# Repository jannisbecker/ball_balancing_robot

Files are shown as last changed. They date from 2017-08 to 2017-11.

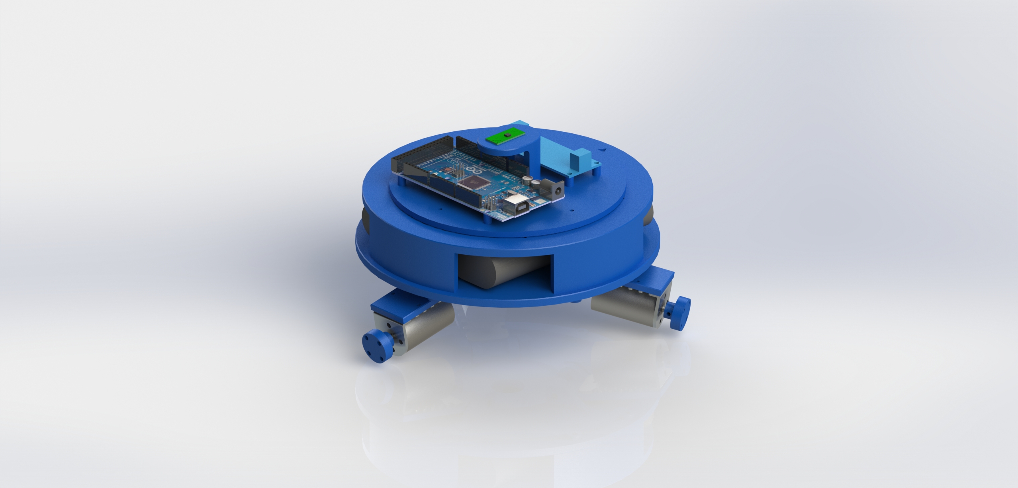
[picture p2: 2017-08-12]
cad/rendering2.jpg

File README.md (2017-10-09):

Repo imported from my old account https://github.com/kekx/ball_balancing_robot

# Ball Balancing Robot

A project made and built by two people, Jannis Becker and Susanne Totz,
in the 6th semester of "Visual Computing and Design" at the Hochschule Hamm-Lippstadt in Germany.

More info on the given task, the project itself and the challenges we faced
can be found in the technical documentation.

## File tree

* **additions**
  * **arduino test sketches:** contains various little code snippets used to test hardware functionality and software concepts.
  * **gyro calibration utility:** java source for a serial data plotter used for calibrating the IMU. More info in the tech doc.
* **cad:** Contains the most recent set of SolidWorks 2017 project files. "Bottom Plate Rework Assembly.SLDASM" being the main file to be opened here.
  * **old versions:** Previous prototypes of the design, including a now unused omniwheel design and the first and second prototype iterations.
  * **thin plates:** Modified files that ended up being used, as the thick plates of the original design couldn't be printed. As seen in the media files, we ended up using thin printed parts and filling the space up with 3mm wooden plates.
* **doc:** The technical documentation containing lots of further insights into the project (German).
* **media:** Videos and photos of the final robot build.
* **src:** Final arduino code.

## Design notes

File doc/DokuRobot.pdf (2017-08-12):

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

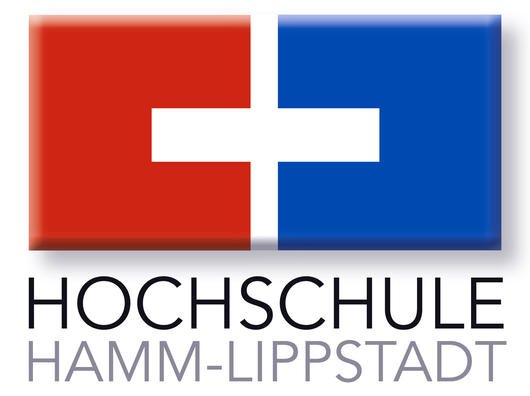
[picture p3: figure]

## Inhaltsverzeichnis

1 Einleitung | 1
2 Problembeschreibung | 2
3 Realisierung des Ball Balancing Robot | 4
4 Fazit | 21
5 Sonstiges | 24
Anhang | 25

I

## 1 Einleitung

Im Rahmen des Wahlpichtfaches Ubiquitous Computing im 6. Semester des Studiengangs

Computervisualistik und Design ist das Projekt Ball Balancing Robot entstanden. Die Auf-

gabenstellung besagte, dass die Studenten zusammen in Gruppen einen Hardwareprototypen

planen, bauen und letztlich mit einer eigens entwickelten Software lauähig machen sollen. Die

Wahl des Themas und der Systemumgebung war den Studenten dabei selbst überlassen. Als

Hilfestellungen konnten Internetquellen und Literatur verwendet werden.

Das Ziel dieses Projektes war es, einen mobilen Roboter zu entwickeln, der eigenständig auf

einem Ball balancieren und sich bei einer externen Krafteinwirkung auch möglichst selbst wie-

der ausrichten kann. Inspiriert wurden wir hierbei durch ein Projekt an der Tohoku Gakuin

Universität in Tagajo, Japan, geleitet von Dr. Masaaki Kumagai, der zusammen mit einem

Studententeam selbst einen solchen Roboter entwickelt hat. 1

Dieses entwarf eine Plattform, die, angetrieben von drei mit sogenannten Allseitenrädern be-

stückten Schrittmotoren, auf einer mit Gummi beschichteten Bowlingkugel balancieren und sich

auch selbst oder per Steuerbefehl im Raum bewegen kann. Dieser Roboter ist auÿerdem in der

Lage, Objekte mit bis zu 10kg Gewicht zu transportieren und kann damit sowohl eigenständig

oder als maschinelle Unterstützung für den Lastentransport eingesetzt werden.

Die zugrunde liegende Funktionsweise eines solchen, sogenannten omnidirektionalen Roboters

wurde in den 70er Jahren entwickelt. Heutzutage haben bereits viele Studentengruppen, aber

auch Hobbyentwickler sich einem solchen Projekt angenommen und es existieren zahlreiche

Berichte und Dokumentationen über diese im Internet. So ist auch dieses Team über einige

Internetquellen sowohl auf das Projekt von Dr. Kumagai, als auch andere Nachbauten gestoÿen

und wurde somit inspiriert, selbst einen solchen Roboter zu entwickeln.

1http://spectrum.ieee.org/automaton/robotics/robotics-software/042910-a-robot-that-balances-on-a-ball

Gegenüber anderen beweglichen Robotiksystemen hat eine omnidirektionale Plattform einige

entscheidende Vorteile. So können diese ohne Verzögerung und jegliche Änderung der Blickrich-

tung direkt in alle Richtungen bewegt werden und sind somit äuÿerst agil. Zudem können diese

Roboter je nach Bauweise sehr klein und mobil gestaltet werden, weshalb sie für zahlreiche

Aufgaben in den unterschiedlichsten Bereichen infrage kommen.

Neben den zu implementierenden Funktionen der Balancehaltung und der Bewegung kann dieses

System auÿerdem noch um viele Funktionen erweitert werden, wie z.B. das ferngesteuerte oder

autonome Fahren, sowie weitere Sensorik und Aktorik.

## 2 Problembeschreibung

In diesen Abschnitt wird kurz dargestellt, welche Quellen das Team nutzt, um den Balancing

Robot zu realisieren. Ebenso werden die Risiken erläutert, die während der Implementierung

Hard- und Software auftreten können.

Die grundlegende Architektur lehnt sich an das Projekt von Dr. Kumagai an, da diese eine

sehr gut funktionierende, aber auch vergleichsweise einfach zu implementierende Basis bildet.

So werden drei Motoren und Räder verwendet, angeordnet in einem 120◦ Winkel zueinander.

Es gibt durchaus auch einige Ansätze, welche zwei oder vier Antriebe verwenden würden, wobei

wir ersteres aufgrund der fehlenden Stabilität und letzteres wegen dem zusätzlichen Kostenauf-

wand sowie Stromverbrauch für ungeeignet hielten. Auch die restliche Hardware, wie z.B. die

benötigte Sensorik und der Mikrocontroller wurden für dieses Projekt eigens ausgewählt, um

optimale Kompatibilität mit unserer Plattform und der gewählten Umgebung zu gewährleisten.

Die Verarbeitung und Ansteuerung in der Software funktioniert grundlegend wie folgt: Zuerst

wird ein Lagesensor nach der aktuellen Rotation des Roboters gefragt. Diese Daten werden

dann in einem Regler weiter verarbeitet und zuletzt an die Motoren gegeben, die eine Schief-

lage dann ausgleichen. Dieser Ablauf ndet viele Male pro Sekunde statt, sodass der Roboter

seine Position und Rotation kontinuierlich ausgleicht.

Die Risiken in der Implementierung der Software stecken vor allem darin, dass der Datenuss

nicht einwandfrei funktionieren könnte. Die Messdaten enthalten Schwankungen und können

von der Nullposition abdriften. Dies gilt es zu erkennen und zu beseitigen. Auÿerdem müssen

mathematische Konventionen, Wertebereiche und Standards deniert werden, welche in allen

Datenströmen und Interfaces zwischen der Sensorik, Verarbeitung und Aktorik eingehalten

werden müssen. Ein falscher Wertebereich oder ein Vertauschen von Datenströmen kann hier

bereits zu einem sehr willkürlich wirkenden Verhalten des Roboters und daraus folgend einem

sehr aufwendigen und zeitintensivem Debugprozess führen.

Da diese Roboter kontinuierlich gegen Schwankungen in jegliche Richtungen, als auch gegen die

Schwerkraft arbeiten muss, sollte bei der Gestaltung des Gerüsts und dem Einbau der Hardware

insbesondere auf die radiale Gewichtsverteilung, aber auch die Verteilung in unterschiedlichen

Höhen geachtet werden. Eine falsche Aufteilung kann hier entweder zu einem nicht genügend

trägen Verhalten führen, da eine gewisse Trägheit für das System benötigt wird, oder aber zu

einem radialen Ungleichgewicht führen, welches die Steuerung des Roboters prinzipiell sehr viel

schwieriger, wenn nicht sogar unmöglich machen würde.

Das Zeitmanagement ist gerade besonders bei Projekten wichtig, in dem vorwiegend Studenten

zusammen arbeiten, die unterschiedliche Erfahrungen in Umgang mit Software und eingebet-

teten System mitbringen. Die Implementationsphase der Software könnte sich schon aufgrund

der Tatsache verzögern, dass die Programmiersprache C/C++ eingesetzt werden muss und die-

se mit einem gewissen Lernaufwand verbunden ist. Die Beschaung der Hardwarebestandteile

sowie das Design des Robotergerüsts benötigen zusätzlich Zeit, weshalb die Entwicklung des

Roboters in unterschiedlichen Phasen unterteilt wird, damit das gesamte Projekt fristgerecht

abgeschlossen werden kann.

## 3 Realisierung des Ball Balancing Robot

In diesem Teil der Ausarbeitung werden die Umsetzungsphasen im Projekt Balancing Robot

aufgegrien und beschrieben. Die Phasen fanden teilweise parallel statt und können somit nur

eingeschränkt unabhängig von einander betrachtet werden.

3.1 | Entwicklung der Gestalt des Roboters
3.1.1 | Allgemein

Folgende Punkte sind bei der Gestaltung des Ball Balancing Robot zwingend zu beachten, um

die Funktionsfähigkeit des Roboters zu gewährleisten:

- Der Roboter benötigt in alle Richtungen eine gleichmäÿige Gewichtsverteilung, damit er
| seine eigene Masse auf dem Ball ausbalancieren kann.
- Die Einbettung des Hardwaresystem mit seinen gesamten Bestandteilen benötigt viel
| Platz, daher ist dieser Sachverhalt bei der Erstellung des Robotergerüsts zu berücksich- tigen. Idealerweise sollte der Roboter nicht in die Breite, sondern in die Höhe, mithilfe mehrerer Ebenen für die verschiedenen Komponenten, gestaltet werden. Somit wird auch die Verwendung kleinerer Bälle ermöglicht und der Roboter ist allgemein mobiler und agiler.
- Die Gewichtsverteilung auf den Ebenen spielt ebenfalls eine wichtige Rolle, um den Ro-
| boter vor dem Umkippen zu bewahren. Eine möglichst hohe Trägheit im Vergleich zum Ball gewährleistet, dass der Ball sich unter dem Roboter bewegen kann, und somit ei- ner Übersteuerung der Motoren entgegen gewirkt wird. Auÿerdem lieÿe sich eine externe Steuerung des Roboters andernfalls nicht realisieren. Dazu müssen die schweren Akkus möglichst weit unten nahe am Ball platziert werden und die leichte Elektronik und Sen- sorik nden weiter oben ihren Platz. Zusätzlich bewirkt ein Platzieren des Lagesensors in gröÿerer Entfernung zum Ball einen gröÿeren Ausschlag der Werte, was eine einfachere Auswertung und eine direktere Steuerung ermöglicht.

3.1.2 Prototyp 1

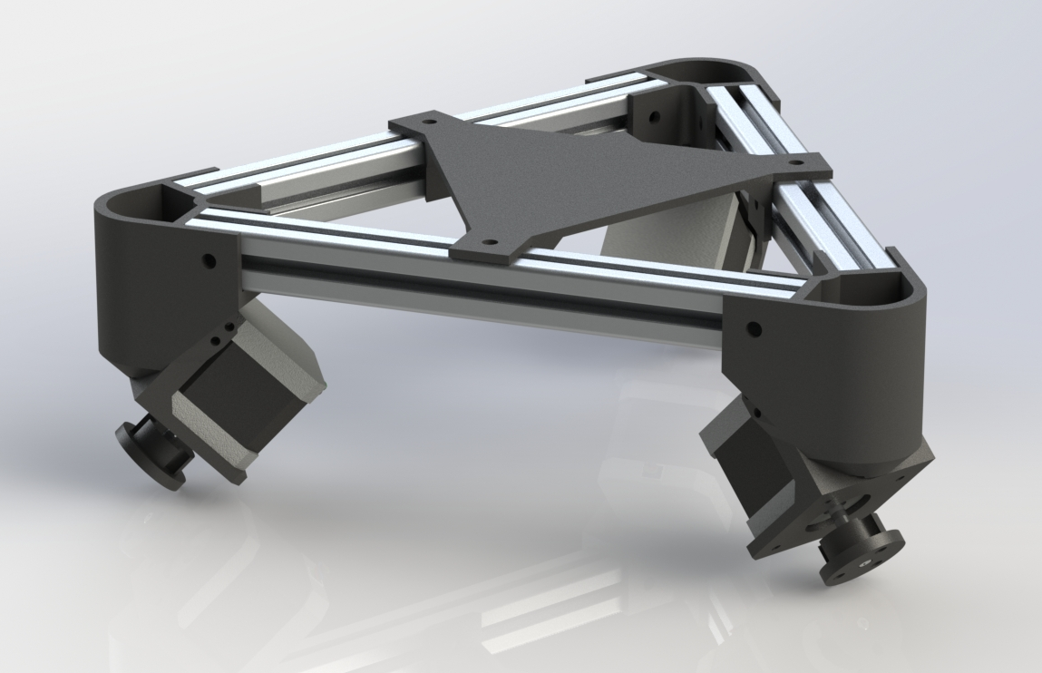
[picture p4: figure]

Abbildung 1: Der nicht vollendete erste Prototyp

Der erste Prototyp (Abb. 1) basierte einer dreieckigen Basis, die aus 20*20 mm groÿen Ex-

trusionsprolen aus Aluminium bestand. Dieses Grundgerüst war an die sehr ähnliche, übliche

Bauweise von Delta 3D-Druckern angelehnt. Der Prototyp war optimiert für den Einsatz

von Schrittmotoren (siehe Abschnitt Hardware). Die Motoren wurden dabei auf drei Schlitten

montiert, die in einem 45◦ Winkel an das Robotergehäuse angebracht sind. Der Vorteil dieser

Montage ist die einfache Wartbarkeit. (Abb. 2) Das Hardwaresystem, sowie alle anderen not-

wendigen Bestandteile wie die Stromversorgung nden ihren Platz in der mittleren Plattform

und der darunter liegenden Ebene.

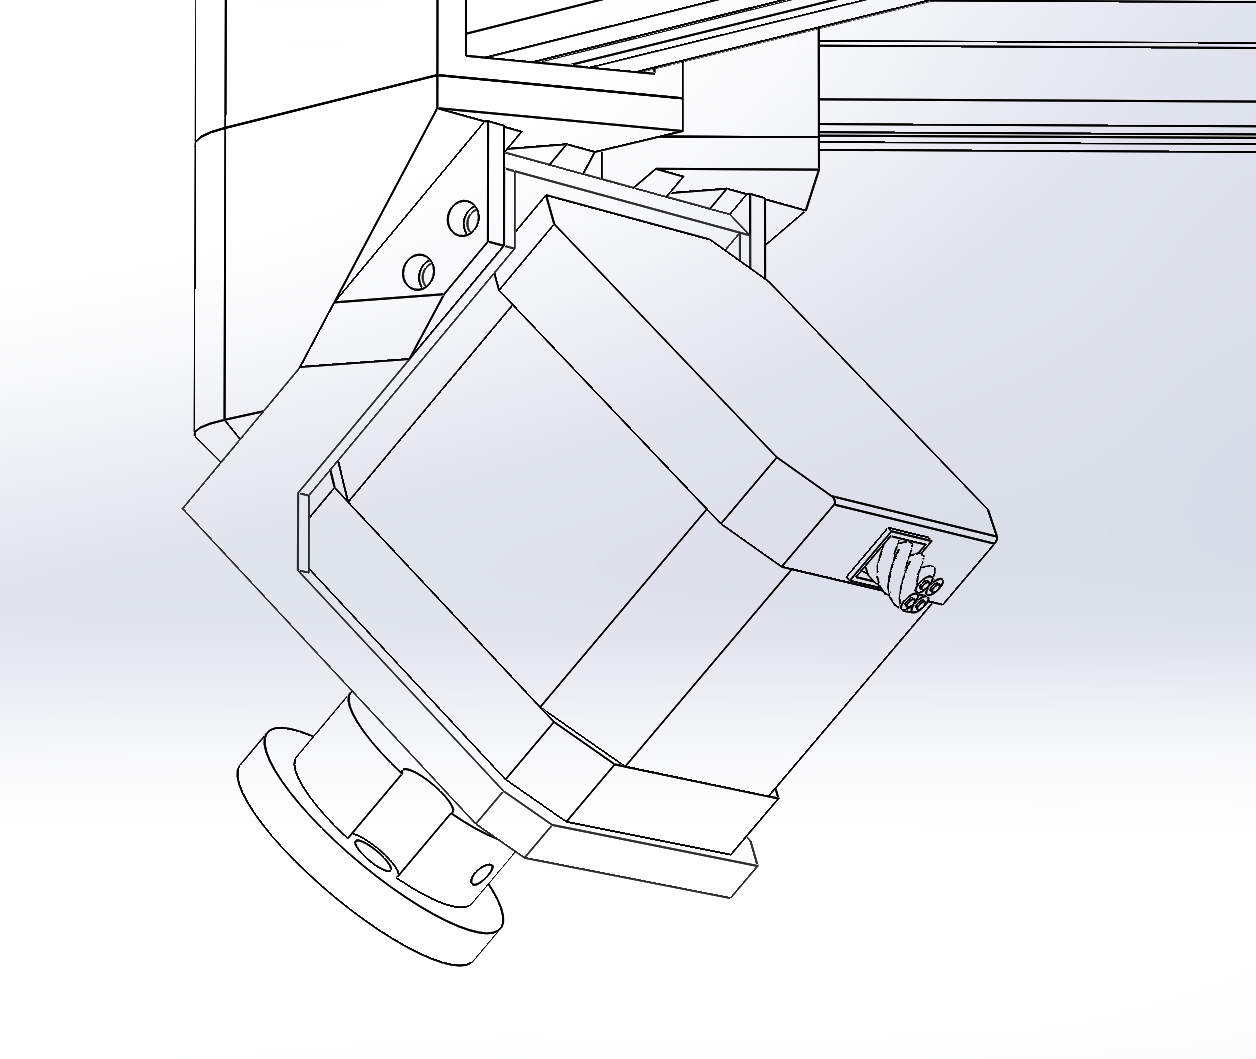
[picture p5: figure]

Abbildung 2: Die Befestigung des Motors beim ersten Prototyp

Folgende Vorteile erhoten wir uns von diesem Prototypen:

- Die Aluminiumprole waren bereits vorhanden, somit hätten weniger Teile nachproduziert

(gedruckt) werden müssen.

- Das Gehäuse bestünde aus Aluminium und wäre damit sehr stabil und widerstandsfähig.
- Durch den Einsatz von starken Schrittmotoren wäre ein Lastentransport möglich gewesen.

Durch die folgenden Nachteile haben wir uns jedoch gegen die Nutzung dieses Prototyps ent-

schieden:

- Die gesamte Konstruktion wäre sehr groÿ gewesen. Die vorhandenen Prole sind 20cm

lang, woraus sich ein Gesamtdurchmesser von etwa 30cm ergibt. Da der Ball somit eben-

falls gröÿer ausfallen muss, gäbe es einen groÿen Einbuÿen in der Mobilität des Roboters.

- Das hohe Gesamtgewicht der Konstruktion und der Schrittmotoren u.A. hätten die Be-

wegung erschwert und das System weniger reaktionsfähig gemacht.

- Da der Fokus bei dieser Variante auf der Breite statt auf der Höhe liegt, wären die Trägheit

und die Gewichtsverteilung des Systems nicht optimal gewesen und die Ausbalancierung

der Komponenten würde erschwert.

3.1.3 Prototyp 2

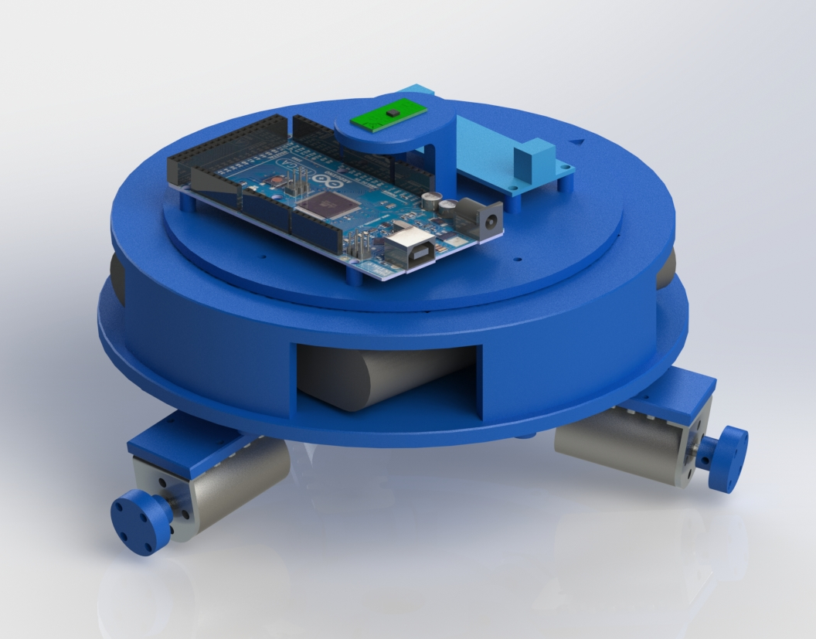
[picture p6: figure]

Abbildung 3: Das Rendering des vollendeten zweiten Prototyps, inklusive der meisten Hardware

Aufgrund der Nachteile der ersten Variante ist die Entscheidung gefallen, ein kreisförmiges

Grundgerüst zu entwerfen (Abb. 3), bestehend aus leichtem, jedoch stabilem Kunststo, welches

vollständig mithilfe eines 3D-Druckers hergestellt werden kann. Die direkte Verfügbarkeit dessen

begünstigte diese Entscheidung wesentlich.

Der Prototyp Nr. 2 hat die folgenden Vorteile gegenüber dem ersten:

- Die Grundform des Gehäuses eignet sich besser zum Anordnen der Hardwarebestandteile

und der Stromversorgung.

- Die mehrschichtige Konstruktion lässt eine präzisere, vertikale Gewichtsverteilung zu

(Trägheitsoptimierung) und ermöglicht eine bessere Balance in der Horizontalen.

- Sehr viel schmaler, mit eng aneinander liegenden und justierbaren Motoren, daher ist

dieser Prototyp für viele Ballgröÿen geeignet.

- Die Konstruktion ist insgesamt leichter, kleiner und agiler, dies sorgt dafür, dass die

Reaktionen schneller und die Bewegung üssiger sind.

Jedoch gibt es auch hier den folgenden, jedoch vernachlässigbaren Nachteil:

- Die Konstruktion ist aufgrund der gewählten Materialien etwas instabiler. Somit ist even-

tuell der Lastentransport nicht gewährleistet. Trotz der Kunststokonstruktion ist aber

mit Hilfe von Verstärkungsrippen, Verrundungen u.Ä. für ausreichende Stabilität gesorgt.

3.1.4 Aufbau des Prototyp 2 im Detail

Im Folgenden ist der grundlegende Aufbau der einzelnen Ebenen des zweiten Prototyps be-

schrieben. Die Ebenen werden hier einzeln von unten nach oben betrachtet.

1. Abb. 4: Drei Motoren inklusive Halterungen und angebrachten Adaptern für die Rä-
| der, befestigt mit drehbaren Verbindungen an der unteren Grundplatte. Zu sehen sind
| hier auÿerdem die Verstärkungsrippen, die Schraubenlöcher zur Befestigung der weiteren
| Schichten, sowie das zentrale Loch für die Kabelführung.
2. Abb. 5: Obere Grundplatte, inklusive äuÿeren und inneren Stelzen, damit zwischen
| oberer und unterer Platte Hardware untergebracht werden kann. Auch hier sieht man das
| zentrale Loch für die Kabelführung, die benötigten Schraublöcher, sowie weitere, eckige
| Löcher, welche später Kabelbinder führen, um die Akkupacks zu befestigen.
3. Abb. 6: Weiterhin die obere Grundplatte, Ansicht von oben. Hier sieht man sehr gut die
| Vertiefungen für die Kabelbinder, damit direkt darauf auiegend die weiteren Ebenen
| befestigt werden können. Eine pfeilförmige Vertiefung symbolisiert die mathematische
| Vorderseite des Roboters.
4. Abb. 7: Befestigungsplatte mit Abstandshaltern, auf dem der Arduino Mega und der
| Spannungsregler befestigt werden. Der Kabelkanal wird hier zu einem Langloch, um das
| seitliche Herausführen der Kabel auf dieser obersten Ebene zu ermöglichen. Nicht alle
| Abstandshalter sind vorgebohrt, da die entsprechenden Schraubenlöcher auf dem Arduino

durch zu kleine Abstände den SMD-Bauteilen nicht für Schrauben genutzt werden können.

Hier wird der Arduino dementsprechend nur aufgelegt. Die beiden Löcher neben der

Kabelführung verbinden später den sogenannten Gyroturm mit dieser Platte.

5. Abb. 8: Der Gyroturm dient der Befestigung des Gyrosensors auf einer erhöhten Ebene,

um dessen Präzision und die Reaktionsfreudigkeit des Gesamtsystems zu erhöhen. Das

rechteckige Loch auf der Oberseite besitzt ähnliche Maÿe wie die Stiftleiste unter der

Gyrosensorplatine und hält diesen somit in Position. Die entsprechenden Pins stehen nun

aus der Unterseite des Turms hervor, wo sie per Jumperkabel mit dem darunterliegenden

Arduino verbunden werden können. Das Loch und der Turm selbst sind so platziert, dass

der eigentliche Gyrosensor IC auf seiner Platine möglichst exakt mittig über dem Roboter

liegt, sodass X und Y-Rotation des Sensors bei einer Bewegung gleichmäÿig ausschlagen.

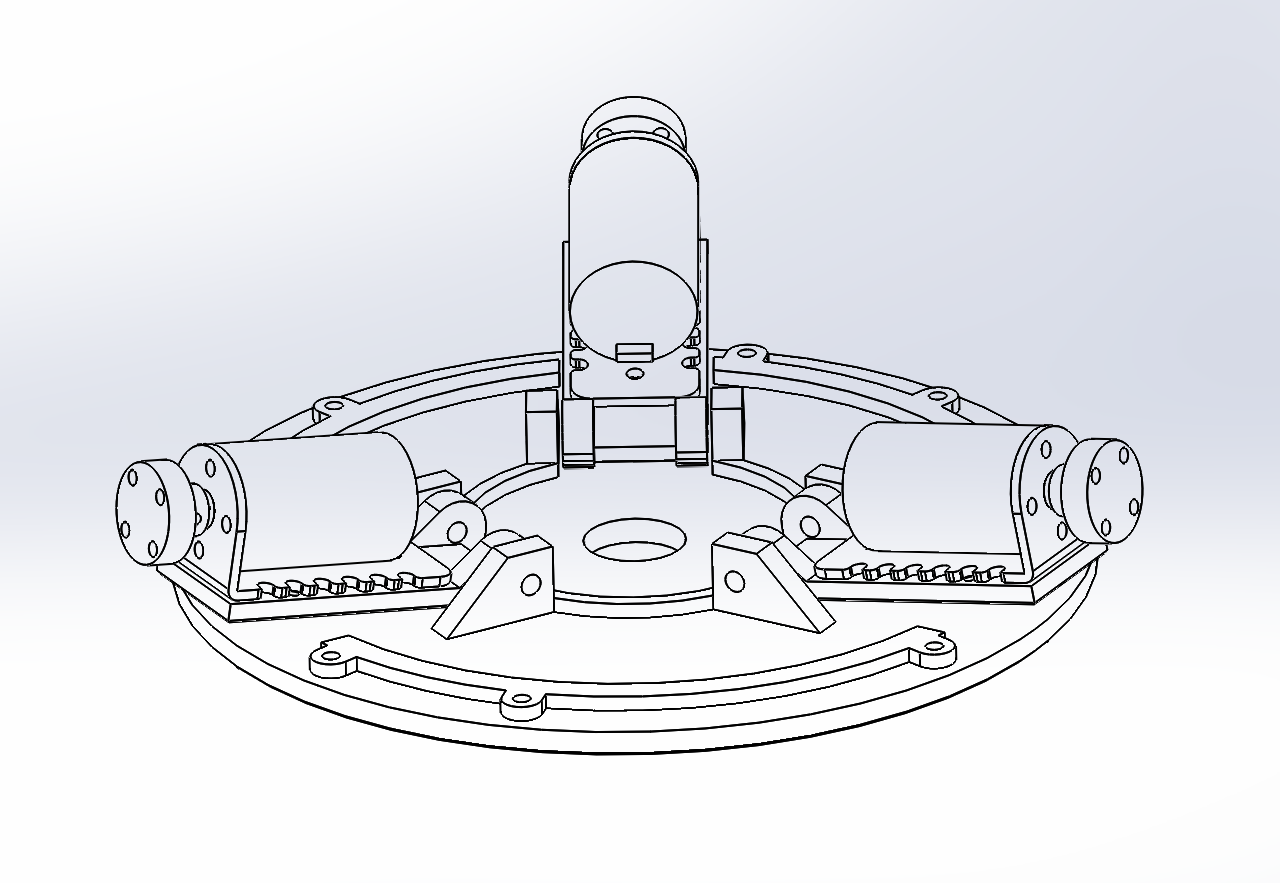
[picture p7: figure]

Abbildung 4: Eine Skizze der unteren Grundplatte, inklusive Motoren und Halterungen, Ansicht von Unten

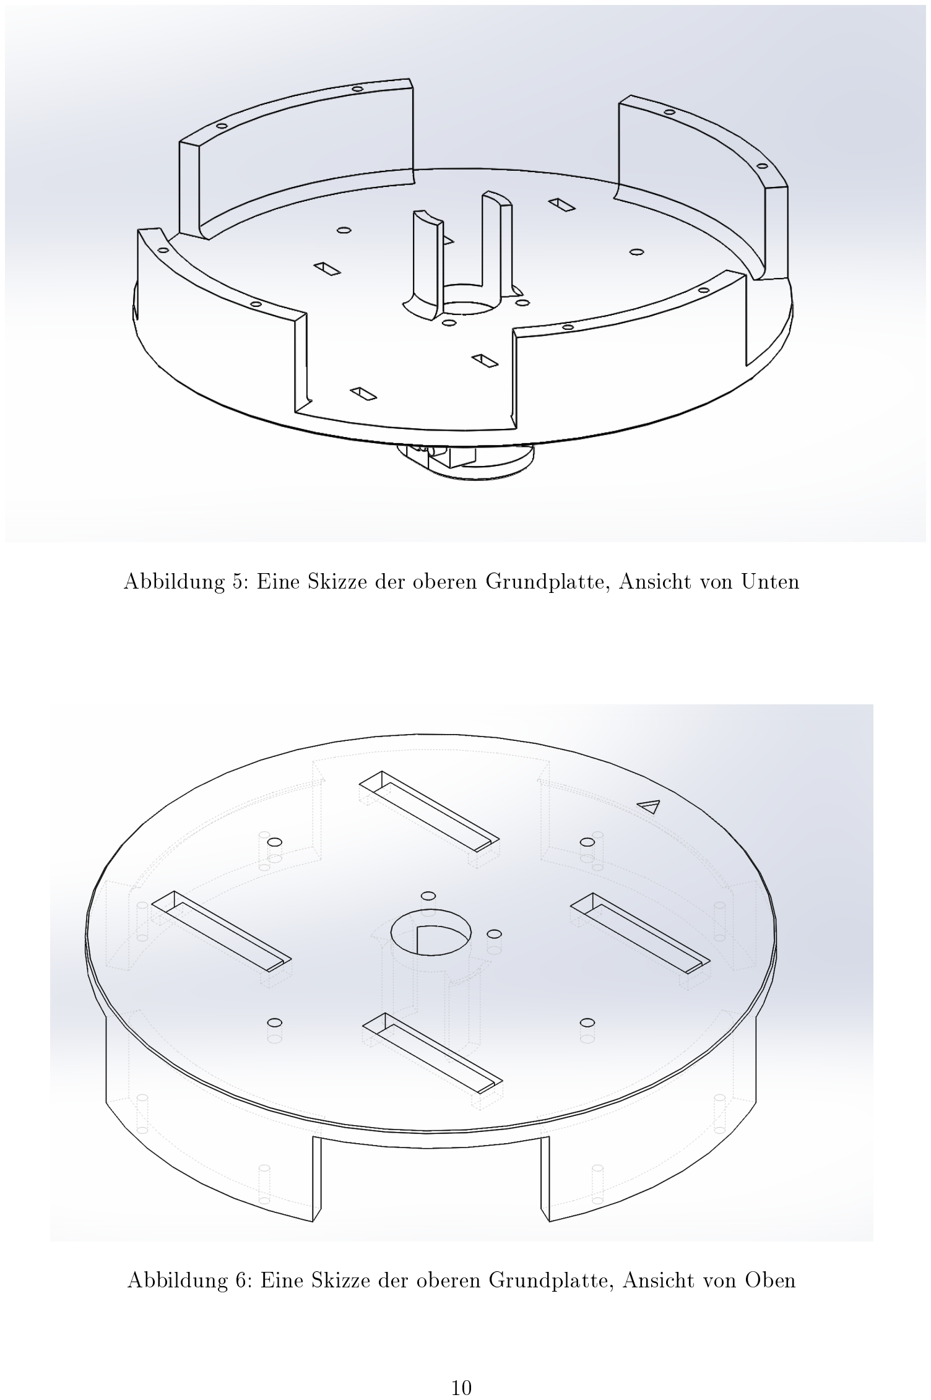
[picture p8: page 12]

Abbildung 5: Eine Skizze der oberen Grundplatte, Ansicht von Unten

Abbildung 6: Eine Skizze der oberen Grundplatte, Ansicht von Oben

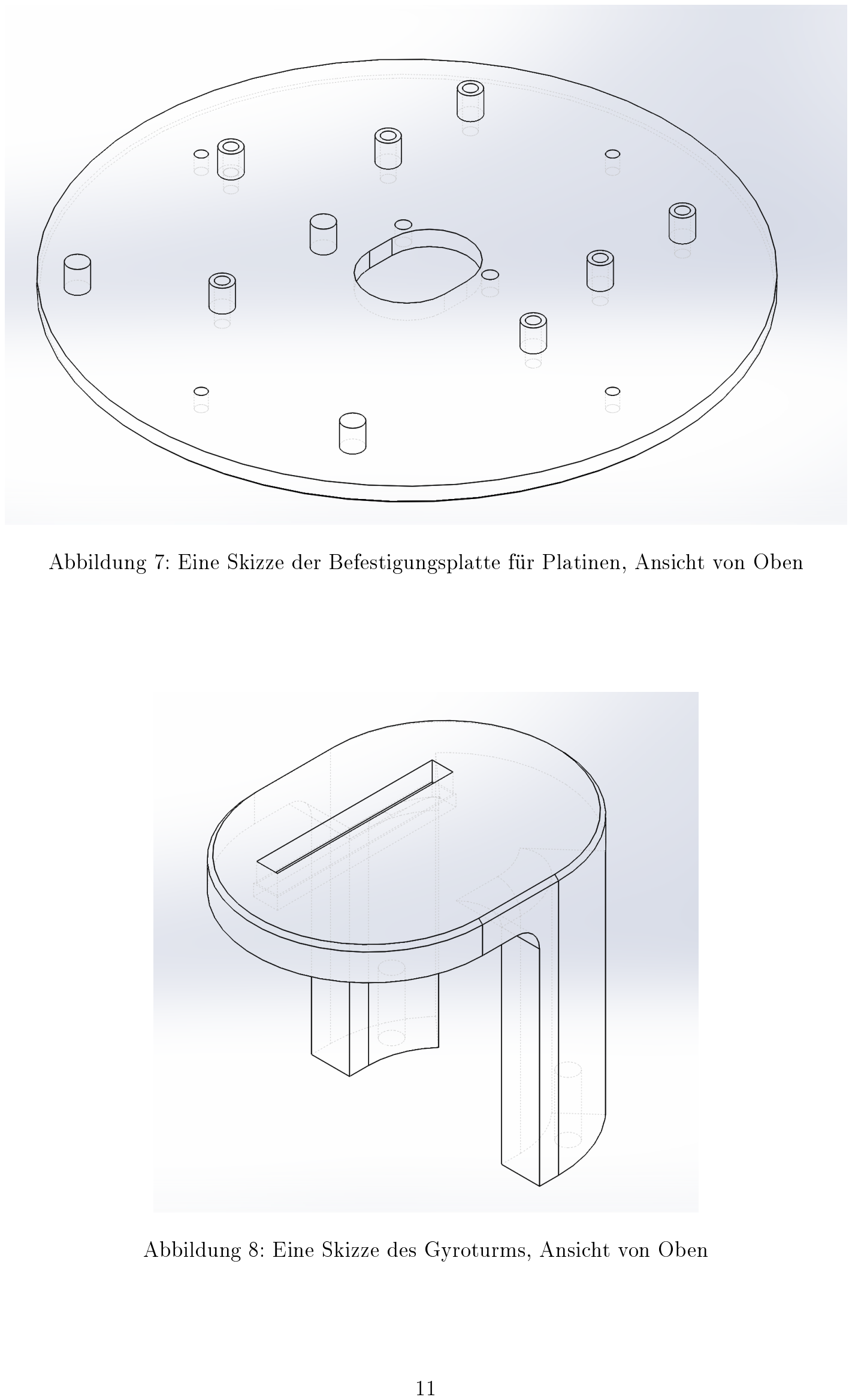
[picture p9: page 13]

Abbildung 7: Eine Skizze der Befestigungsplatte für Platinen, Ansicht von Oben

Abbildung 8: Eine Skizze des Gyroturms, Ansicht von Oben

Einige weitere Ansichten, um den Zusammenbau zu verdeutlichen:

6. Abb. 9: Gesamtaufbau, Ansicht von unten. Hier deutlich zu sehen sind die Verbindungen

von oberer und unterer Grundplatte, die Positionen der Akkus und der Motoren zuein-

ander. Auch interessant ist der Wechsel von den dreieckig angeordneten Motoren auf der

Unterseite zu einem viereckigem System im Mittelteil, dass durch die sperrigen Akkus

erzwungen wird.

7. Abb. 10: Gyroturm, befestigt auf der Platinenebene sowie der oberen Grundplatte, in-

klusive Arduino Mega und Stepdown Wandler. Hier ist die genaue Position des Gyro ICs

über dem kreisförmigen Kabelkanal gut zu sehen, sowie die Austragung zum Langloch in

Richtung der Vorderseite, da der Arduino etwa die Hälfte des Kabelkanals durch seine

Gröÿe bereits verdeckt.

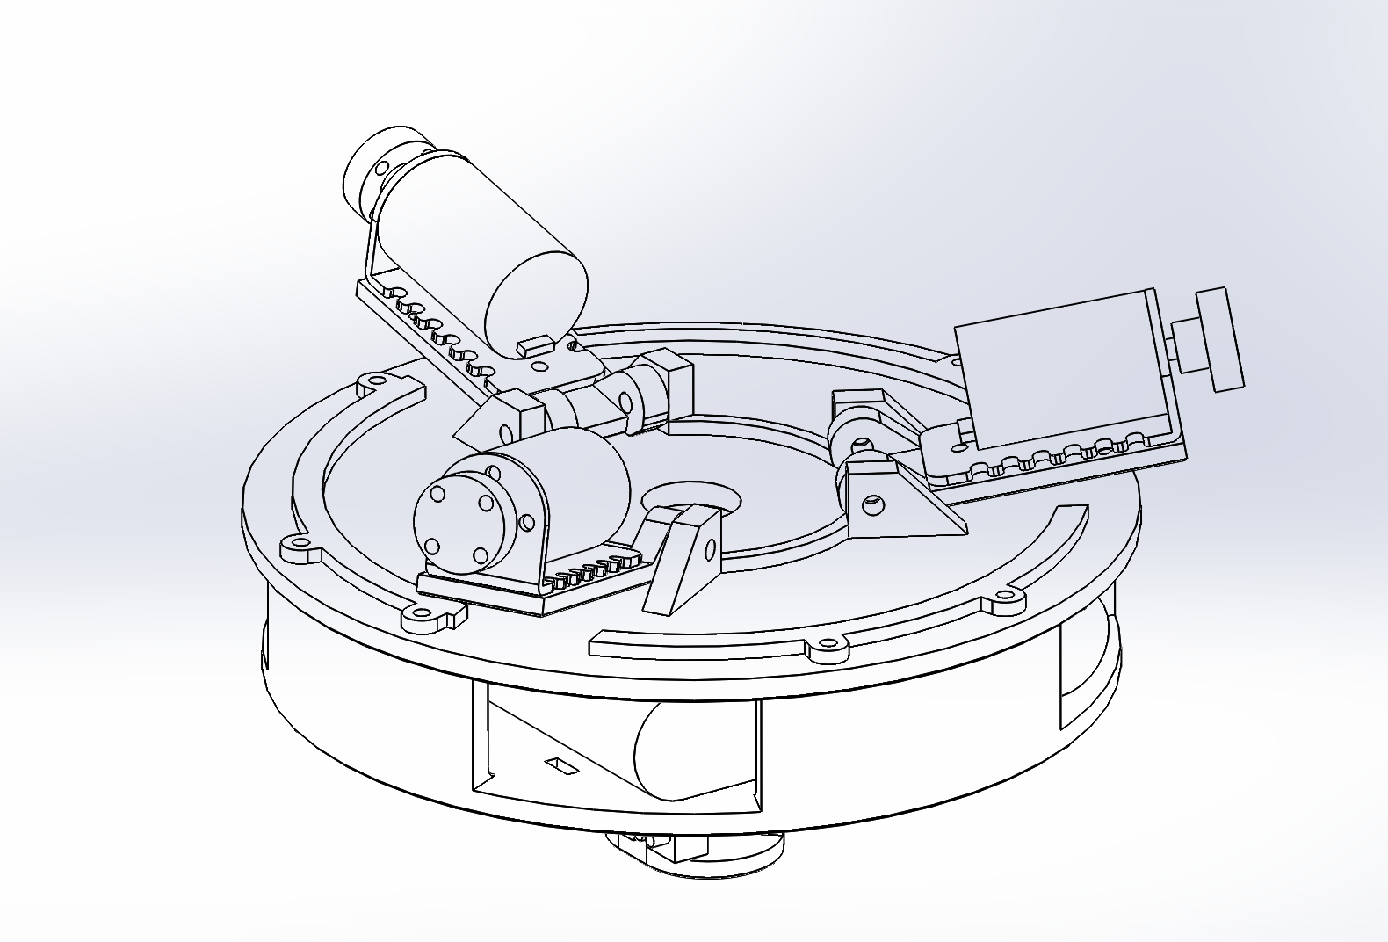
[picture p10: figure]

Abbildung 9: Eine Skizze des Gesamtaufbaus, Ansicht von Unten

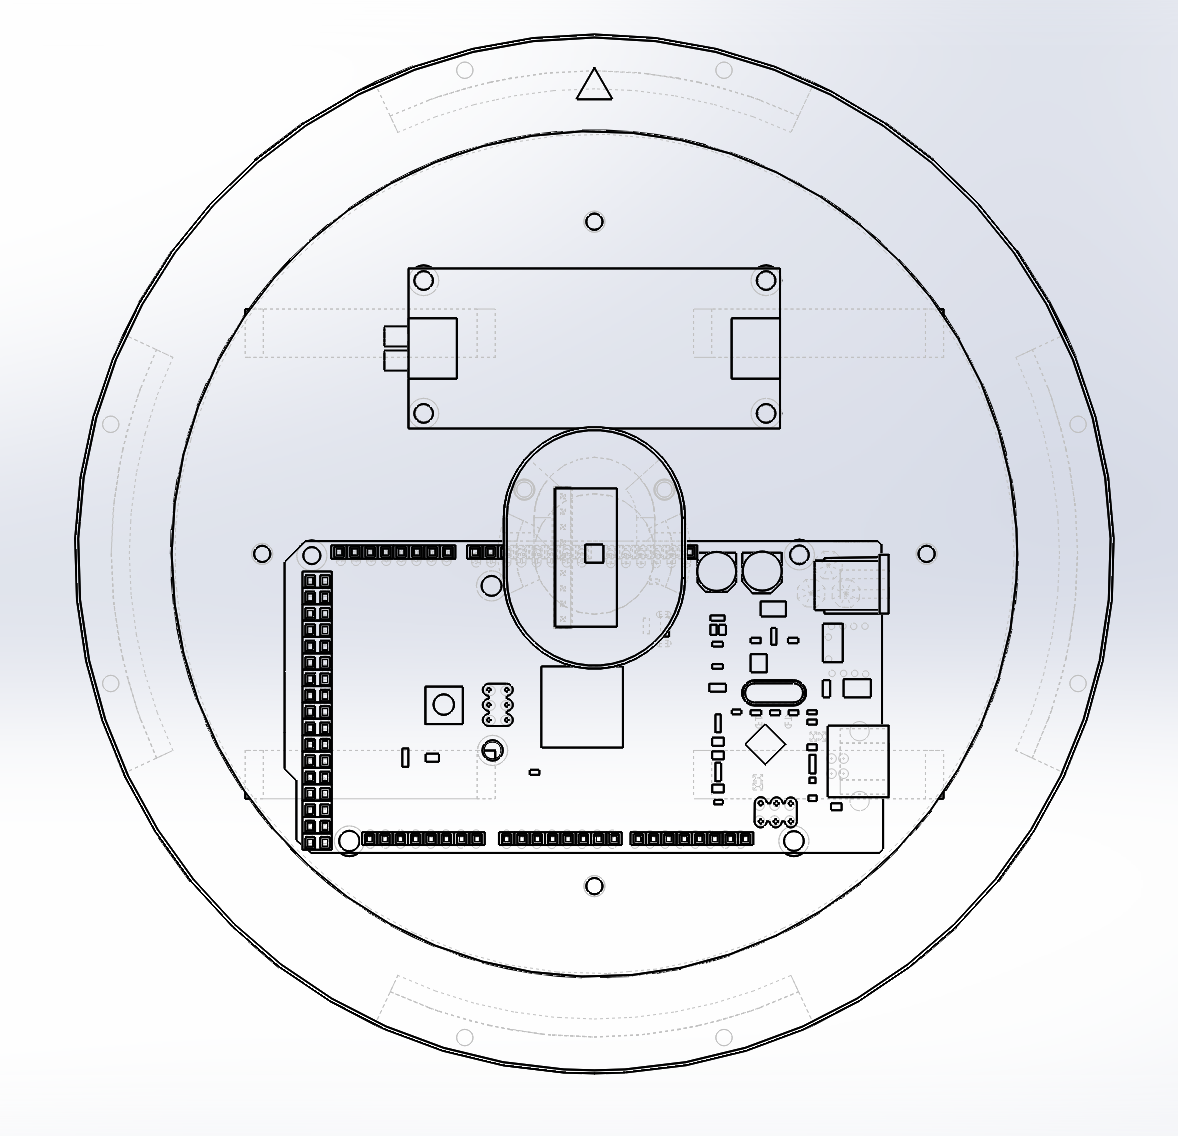
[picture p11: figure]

Abbildung 10: Eine Skizze des befestigten Gyroturms auf der PCB Platte und oberer Grundplatte, Ansicht von Oben

3.2 | Aufbau des Hardwaresystems
3.2.1 | Allgemeines

Zeitgleich mit der Entwicklung der Gestalt kam auch die Frage nach der Hardware auf. Beim

ersten Prototypen plante man mit der Verwendung von NEMA 17 Schrittmotoren, weil diese aus

dem Bereich des 3D-Druck bereits bekannt waren und ein hohes Drehmoment und sehr präzise

Bewegungen erzielen können. Nach einigen Tests mithilfe eines DRV8825 Schrittmotortreibers

(ebenfalls üblich im 3D-Druck) elen aber sofort die Probleme des Systems auf. Zum einen

sind Schrittmotoren nicht unbedingt dafür ausgelegt, sehr viele, schnelle Bewegungswechsel

zu vollziehen, insbesondere, wenn ein Wechsel von einer hohen Drehzahl aus stattnden soll.

Andererseits verlieren diese Schrittmotoren bei hohen Drehzahlen gerne einzelne Schritte, oder

drehen sich gar nicht mehr. Ein plötzliches Auftreten dieses Problems im endgültigen Roboter

wäre fatal, weshalb das Team entschied, diesen Ansatz nicht weiter zu verfolgen. Da aber der

Roboter von Dr. Kumagai ebenfalls erfolgreich Schrittmotoren (NEMA 23) verwendet, stellt sich

die Frage, ob es nicht vielleicht an den getesteten Schrittmotoren, oder aber an der benutzten

AccelStepper Library liegt.

Mit dem Wechsel zum zweiten Prototypen mit seinm kleineren Kunststogerüst hatte sich

die Frage nach den Motoren sowieso erübrigt. Nun kommen DC (Gleichstrom) Motoren zum

Einsatz, welche kleiner, leichter und trotz dessen für ihre Gröÿe stark und schnell genug sind.

DC-Motoren bieten den Vorteil, dass sie für eine Maximalgeschwindigkeit ausgelegt sind, die

sie immer und sicher erreichen können, somit sind zu hohe Geschwindigkeiten kein Problem.

Des weiteren sind sie sehr agil und für schnelle Richtungswechsel ausgelegt.

3.2.2 | Bestandteile der Hardware
3.2.2.1 | Mikrocontroller

Das Rechensystem des Roboters bildet ein Arduino Mega 2560 rev 3. Dieser bietet ausreichende

Leistung für den Roboter, da dieser etwa 100 Mal pro Sekunde einige ausführliche Berechnungen

vollführen muss. Zudem sind alle nötigen Anschlüsse in genügender Zahl vorhanden und die

zusätzlichen Anschlüsse, sowie die reichlich vorhandene Leistung bieten genug Spielraum für

Erweiterungen.

3.2.2.2 Gyrosensor

Die Rotation des Roboters wird durch einen sogenannten Gyrosensor, genauer gesagt dem

Modell LSM6DS33 von Polulu erfasst. Dieser kann per Serial oder SPI Schnittstelle mit dem

Arduino ohne groÿen Aufwand verbunden werden und besitzt einen integrierten Spannungs-

wandler, sodass das Betreiben an einem 5V Arduino kein Problem darstellt.

3.2.2.3 Motoren und Räder

Der im Ball Balancing Robot verwendete Motor, mit der Nummer FIT0441 von DFRobot,

bietet neben den bereits genannten Vorzügen der DC-Motoren zusätzlich den Vorteil, dass der

benötigte Motortreiber, als auch ein (in diesem Projekt nicht verwendeter) Encoder direkt im

Motor integriert sind, so dass diese ausschlieÿlich eine 12V Versorgung und einen Microcontroller

benötigen.

Unverständlich war dagegen der Aspekt, dass diese, eigentlich für das Prototyping ausgelegten

Motoren mit JST-Steckern versehen waren, welche nicht mit den für das Prototyping üblichen

Dupont Stecksystemen kompatibel sind. Hier wurden kurzerhand in mühevoller Handarbeit die

Buchsen gegen Dupont Varianten ausgetauscht, um den weiteren Zusammenbau erheblich zu

erleichtern.

An die Motoren angeschlossen sind insgesamt drei Allseitenräder, genannt Omni Wheels, in der

38mm Ausführung von noDNA. Es ist zwar eine 60mm Ausführung erhältlich, diese war aber

zum Zeitpunkt des Einkaufs nicht verfügbar. Es könnte aber gut möglich sein, dass die Motoren

mit den 60mm Rädern zu wenig Kraft aufbringen können, deshalb sollte lieber auf die kleinere

Variante zurückgegrien werden.

3.2.2.4 Akkus und Stromversorgung

Versorgt wird die Elektronik von zwei 7.2V 2400 mAh NiMh Akkupacks aus der Modellbau

Branche, welche in Reihe geschaltet etwa 14-15V liefern. Diese Spannung wird durch einen

XL4015 Spannungswandler (Step Down) auf stabile 12V reduziert und dann an den Arduino

und die Motoren gegeben.

3.2.3 | Hardware in der Gestalt
3.2.3.1 | Aufteilung

Wie im Kapitel der Gestalt bereits erwähnt, ist eine intelligente Aufteilung essentiell für die

einwandfreie Funktion des Roboters. Einerseits sollten die einzelnen Komponenten, insbeson-

dere jedoch die schweren Motoren und Akkupacks mit Bedacht ausbalanciert werden, damit

der Roboter sein Gleichgewicht halten kann und andererseits sollte auch auf die Aufteilung in

der Vertikale geachtet werden, denn bspw. ein Einbau der Akkupacks in höheren Ebenen würde

den Roboter sehr viel anfälliger für das Umkippen auf dem Ball machen, während ein Einbau

möglichst weit unten dies erstens verhindert und zweitens für eine bessere Haftung auf dem

Ball und ein optimales Trägheitsmoment des Roboters sorgt.

In unserem aktuellen Prototyp 2 benden sich die Motoren und Akkus in den untersten Ebe-

nen, nahe am Ball, und die Elektronik ndet weiter oben ihren Platz, wobei insbesondere der

Gyrosensor ganz oben, idealerweise noch erhöht platziert wird, um sein Reaktionsverhalten zu

verbessern. Auÿerdem sollte dieser möglichst exakt mittig platziert werden (mit Fokus auf dem

eigentlichen IC, nicht der Platine), sodass die Messdaten des Sensors gleichmäÿig ansteigen.

3.2.3.2 Kabelführung und Anschluss

In diesem Kapitel sei einmal die Kabelführung im Roboter, von unten nach oben betrachtet,

erklärt.

1. Ganz unten im Roboter benden sich die drei Motoren, mit jeweils einer zweipoligen

Stromverbindung und einem weiteren dreipoligen Kabel für die Übertragung der Ge-

schwindigkeit, Richtung sowie dem Encoderfeedback (in Prototyp 2 unbenutzt). Diese

werden nun durch das Loch der unteren Grundplatte in die zweite Ebene geführt.

2. Dort benden sich die beiden 7.2V Akkupacks, per Y-Kabel in Reihe geschaltet. Das

daraus entspringende Kabel (nun mit 14-15V) wird, zusammen mit den Motorkabeln,

durch das nächste Loch, weiter nach oben geführt.

3. Durch die obere Grundplatte und die PCB Befestigungsplatte hindurch werden diese

Kabel nun in Richtung Vorderseite (entlang des Langlochs) und unter dem Stepdown

Wandler hindurch geführt und die Kabel der Akkus werden hier mit diesem verbunden.

Die Stromkabel der Motoren werden an den Ausgang (12V) des Wandlers geschaltet,

selbiges gilt für den Arduino. Zuletzt werden noch die Datenverbindungen der Motoren

an den Arduino gesteckt, und der Gyrosensor ebenfalls mit diesem verbunden.

### 3.3 Implementierung der Software

Die Software ist in mehreren Schritten entstanden, da die benötigten Hardwarekomponenten

nicht alle gleichzeitig eingetroen sind. Zuerst kümmerten wir uns um den Gyrosensor und einige

Tests mit den nun verworfenen Schrittmotoren, danach kamen die neuen Motoren und zuletzt

kam die Datenverarbeitung sowie der Zusammenschluss der einzelnen Softwarebestandteile.

Insgesamt lässt sich die Software in 3 Modulen beschreiben, jedes besitzt in der Implementierung

auch eine eigene Klasse: Der Gyrosensor und dessen Verarbeitung, das PID und dessen Regelung

und zuletzt die Motoransteuerung und die Kräfteverteilung

3.3.1 Gyrosensor und Filter

Erfahrungen mit Gyrosensoren waren praktisch gar nicht vorhanden. Um ein Gefühl für die

Empndlichkeit und den Wertebereich des Sensors zu bekommen, wurde zuerst ein Minimal-

programm für den Arduino Mega programmiert, welches die gelesenen Rotations- und Be-

schleunigungsdaten über die serielle Schnittstelle an den Steuerungsrechner überträgt. Um ein

ausreichend schnelles Steuerungsverhalten zu erhalten, muss der Gyro mindestens alle 100ms

ausgelesen werden. Die dabei anfallende Datenut ist jedoch in Textform nicht mehr zu überbli-

cken. Daher suchten wir eine Bibliothek, um die serielle Schnittstelle und somit die Sensordaten

unabhängig von der Arduino IDE auslesen und visualisieren zu können. Am geeignetsten er-

schien uns ein Visualisierungsprogramm in Java, da wir mit dieser Sprache schon in früheren

Semestern reichlich Erfahrung in der GUI Programmierung sammeln konnten.

Für die Anbindung an den seriellen Bus gibt es unter Java verschiedene Bibliotheken, die jedoch

alle eine native, in C++ programmierte Komponente benötigen. Wir haben uns für nrjavase-

rial entschieden, da diese die nativen Bibliotheken bereits mit bringt und auch selbstständig

verwaltet. Mithilfe des EventListener Pattern wurde eine grasche Anzeige der jeweils über

Schnittstelle empfangenen Daten des Sensors implementiert (Abb. 11). 2

2https://github.com/NeuronRobotics/nrjavaserial

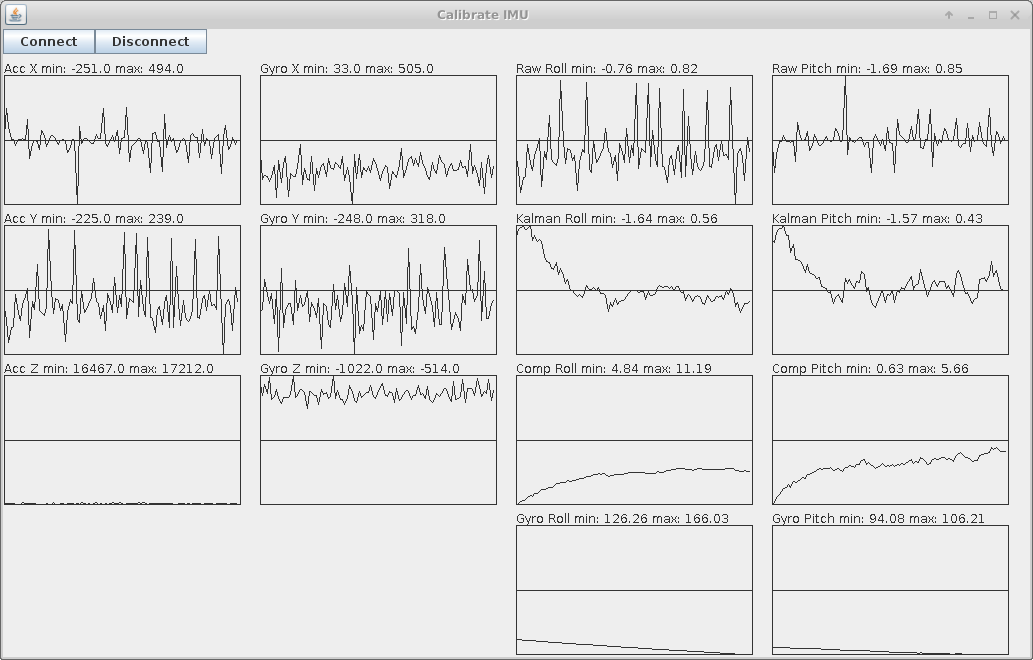
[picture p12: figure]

Abbildung 11: Kalibrierung des Gyrosensors

Die genaue Ausrichtung des Messplatine genau waagerecht oder senkrecht war händisch nicht

möglich. Daher schraubten wir den Sensor temporär auf einen rechtwinkligen Holzklotz. Somit

konnte eine Messung in jede 90◦ Richtung angemessen werden. Dabei stellte sich schnell her-

aus, dass die Daten des Gyrosensor denitiv weiter verarbeitet werden müssen, da sonst ganz

schnell ein Abdriften der Rotationsdaten stattndet. Auÿerdem wurde eine weitere Eigenschaft

des von uns gewählten Sensors durch die Visualisierung deutlich: Die hohe Empndlichkeit er-

zeugte auch ein starkes Messrauschen, welches schon durch kleinste, unbemerkte Vibrationen,

durch Wärmeunterschiede, oder aber durch Spannungsschwankungen entstehen kann.

Es musste also ein Filter eingebaut werden, der die Messwerte glättet und einen Datendrift

verhindert, bevor diese an die Motorregelung weitergegeben werden können. Auch hier gab

es bereits verschiedene Bibliotheken mit unterschiedlich komplexen Filtern. Die Ergebnisse

wurden ebenso wie die Messwerte zur Visualisierung an den Steuerungscomputer übertragen

und bewertet. Nach eingehender Betrachtung schien der Komplementärlter eine ausreichende

Glättung bei beherrschbarer Komplexität aufzuweisen und wurde daher im weiteren Verlauf

verwendet.

Nach der Implementierung des Komplementärlters ist jedoch ein neues Problem ersichtlich

geworden. Da der Komplementärlter die Messwerte über die Zeit integriert, sind etwa die

ersten 200 Messwerte (die ersten 2 Sekunden der Laufzeit) nicht zu gebrauchen, da sich die

Messwerte erst nach und nach der richtigen Kurve annähern. Auÿerdem wurde eine Möglichkeit

gesucht, den Nullpunkt des Sensors neu setzen zu können, so dass sich dieser beim Start bzw.

beim Aufsetzen des Roboters auf den Ball präzise festlegen lässt. Beide Probleme lieÿen sich

mit einer Kalibrierungsmethode lösen, welche zu erst die genannten 200 Messwerte liest und

überspringt, um dann etwa 300 Messproben zu nehmen, den Durchschnitt zu errechnen, und

dies von den, im späteren Programmablauf folgenden Messungen abzuziehen. Dieses Methode

wird zu Beginn des Programmablaufs aufgerufen, womit der Nullpunkt beliebig neu gesetzt

werden kann, und damit die gemessenen Werte nahe dem Nullpunkt auch wirklich nahe Null

liegen.

3.3.2 PID Regelung

Den nächsten Programmabschnitt bildet das PID. PID steht für Proportional, Integral, De-

rivative und bezeichnet eine der am universellsten einsetzbaren Regelungsimplementierungen.

Der PID Regler wird in unserem Fall verwendet, damit sich der Roboter in einem möglichst

weichen Verlauf an den Nullpunkt annähert. Zusätzlich lässt sich dieser durch drei Variablen

beliebig kongurieren, um das Ansteuerungsverhalten des Roboters an die Umgebung anpassen

zu können. In der Implementierung existieren zwei unabhängige, aber identisch kongurierte

PID Regler, jeweils einer für die Rotationen (Abweichungen von der Null-Lage) in X- und Y-

Richtung.

Hier gab es im Projekt lange Zeit Probleme. Zu Anfang gab die Regelung ausschlieÿlich Null-

werte aus, aber dies hatte sich schnell erübrigt. Insbesondere die Findung der richtigen Parame-

terwerte gestaltete sich über den Groÿteil des Projektzeitraumes als schwierig, denn der Regler

war oft am Übersteuern, oder hatte ein hohes Maÿ an Rauschen und viele Datenspitzen (peaks)

im Datenstrom, wobei beides für die Robotersteuerung ungeeignet wäre und zu unerwünschten

Verhalten führen konnte.

Letztlich haben sich sehr schwache Werte als ideal erwiesen. Stattdessen wurde dem Regler

die Datenglättung überlassen, während die Stärke des Motoroutputs über eine weitere Variable

linear und ideal angepasst wurde.

3.3.3 Ansteuerung der Motoren

Der letzte Programmteil kümmert sich um die Auswertung der PID Werte und das letztliche

Ansteuern der Motoren. Da die PID-Regler zwei Werte liefern, die das gewünschte Ansteuer-

verhalten der Motoren in X und Y-Richtung beschreiben, es aber drei Motoren gibt, müssen

diese Koordinateninformationen in einer durchaus komplexen Verarbeitung auf die drei Moto-

ren aufgeteilt werden. Das Grundprinzip ist hierbei aber relativ einfach: Die PID-Regler liefern

zwei Werte, X und Y, die auch als Vektor aufgefasst werden können. In einem Koordinaten-

system kann so nun ein Winkel ausgerechnet werden. Den festgelegten Standards des Projekts

zufolge ergibt ein Vektor in Y-Richtung einen Winkel von 0◦ und der Winkel erhöht sich gegen

den Uhrzeigersinn. Die Y+ Richtung ist als Vorderseite (Siehe Kapitel 3.1.3) des Roboters

deniert, deshalb ergibt es Sinn, hier einen eindeutigen Wert zu erhalten.

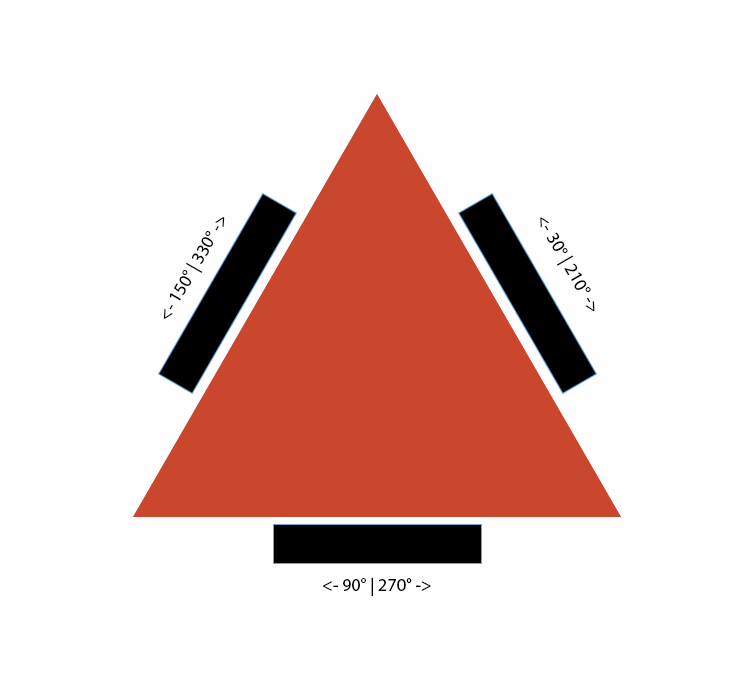
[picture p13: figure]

Abbildung 12: Die einzelnen Stellwinkel der Räder und jeweils beiden Bewegungsrichtungen im Koordinatensystem

In Abb. 12 wird gezeigt, in welche Richtungen die beiden Drehrichtungen jedes Rades im oben

denierten Koordinatensystem zeigen. Sobald nun aus den PID-Daten ein Vektor erstellt und

dessen Winkel im selben System ausgerechnet wurde, kann dieser Winkel nun mit jedem der

gezeigten Winkel verglichen werden. Sollte der Unterschied kleiner als 90◦ ausfallen, so muss

sich das jeweilige Rad in diese Richtung bewegen. Je kleiner der Unterschied ausfällt, desto

stärker wird sich das Rad drehen. Wenn sich z.B. eine Bewegungsrichtung von 330◦
ergibt, wird

sich das Rad vorne links mit der maximalen Geschwindigkeit gegen den Uhrzeigersinn drehen,

das Rad vorne rechts wird sich etwas langsamer (60◦ Dierenz) mit dem Uhrzeigersinn und das

hintere Rad wird sich ähnlich langsam ebenfalls mit dem Uhrzeigersinn drehen (ebenfalls 60◦

Dierenz). Im Programmcode sind dies normalisierte Werte, die nun mit der Länge (Stärke)

des PID Vektors multipliziert und zusätzlich mit einem weiteren einstellbaren Motor Gain Wert

verrechnet werden. So ergeben sich in etwa Werte von 0-255 für jeden Motor, welche dann die

Motorsteuerung per Pulsweitenmodulation an die Motorpins weiterleitet.

## 4 Fazit

Was haben wir aus dem Projekt gelernt? Während der Entwicklungsphase des Ball Balancing

Robot ist das Team mit einigen Problemen konfrontiert worden, die es zu lösen galt. In diesen

Abschnitt der technischen Dokumentation sollen diese Probleme diskutiert werden und alterna-

tive Ansätze kurz dargestellt werden. In der ersten Phase des Prototyping sind zwei Entwürfe

entstanden (siehe Kapitel 3.1.2 und 3.1.3), die mit ihren Vor- und Nachteilen beschrieben wur-

den. Die Wahl el auf den Prototyp 2, der mit Hilfe der 3D Drucktechnik realisiert wurde.

Bereits bei der Anfertigung ist dem Team aufgefallen, dass der Druck der Plattformen mit der

gewünschten Stärke zu lange dauern würde und dass es allgemein Probleme mit dem Druck

gab. Aus diesem Grund wurden die Platten 3mm dünner gestaltet und die Dicke mit 3mm star-

ken Sperrholzplatten kompensiert. Bei der Montage el die geringe Festigkeit des Kunststos

negativ auf, da es schwierig war, stabile Gewinde für die Montage der Adapter für die Räder in

das Plastik einzuarbeiten. Das Gewinde wies nicht die Festigkeit auf, um die Räder stabil auf

der Achse der Motoren zu xieren. Bei einer zweiten Entwicklungsphase würde das Team als

Alternative den Prototyp mit Hilfe einer CNC-Fräse aus Metall fertigen, um so die benötigte

Stabilität und Festigkeit zu gewährleisten.

Der Entwurf des Prototyp hat sich als erstaunlich einsatzfähig gezeigt und es gab insgesamt

wenig Probleme bei Montage der Hardware und des Gehäuses. Dennoch sind einige Anpassun-

gen empfehlenswert, um das Gehäuse zu optimieren. Zum Beispiel wäre die Kabelführung zu

optimieren, da diese gerade ausreichend Platz bot, um alle Jumperkabel und Stromkabel des

Akkus anzuordnen. Ein Bündelung der Kabel je Motor erweist als ebenfalls praktisch, da das

Stecken der Pins somit sehr viel einfacher ist. Hier könnte z.B. auch der Gyroturm etwas erhöht

werden, damit darunter mehr Platz für die Kabelverlegung vorhanden ist. Die Halterung der

Räder wurde so entwickelt, das man diese exibel einstellen kann. Es hat sich dennoch bei der

Testphase des Prototypen herausgestellt, dass sich ein Abstandhalter zwischen Gehäuse und

Motor-Radhalterung als Vorteil erweist. Alternativ hätte man auch eine xe Halterung mon-

tieren können, die auf einem festen Balldurchmesser angepasst ist. Zusätzlich hätte man einen

Ein/Aus Schalter und einen dedizierten Ladeanschluss verbauen können. Das Ein/Ausschalten

funktioniert zu diesem Zeitpunkt noch über das Anschlieÿen eines der Stromkabel, und für das

Laden der Akkus muss der Roboter zum Groÿteil demontiert und nachher wieder zusammen-

gebaut werden.

Die Softwareentwicklung ohne die Hardwarebestandteile hat sich als schwierig erwiesen, da

ein kontinuierliches System einen Datenuss beinhaltet, den es am Anfang zu simulieren galt.

Nach kurzer Zeit wurde jedoch festgestellt, dass der Einsatz der Hardwarebestandteile zwin-

gend notwendig war, um die Software zu entwickeln, sodass diese auch auf das Hardwaresystem

des Roboters übertragen werden kann. Insbesondere das PID System braucht realistische Än-

derungswerte des realen Systems, sonst lässt sich dieses nicht wirklich testen. Der Einsatz

vorhandener Bibliotheken erleichterte zwar die Programmierung, aber dennoch waren in der

Testphase einige Anpassung nötig um die Probleme zu beseitigen. Der Gyrosensor verfügt über

eine eigene Bibliothek, deren Funktionen korrekt sind, dennoch gab es Probleme bei der Kali-

brierung, da die Koordinaten teilweise vertauscht waren. Beim Testen des Gyrosensors an sich

ist dieser Sachverhalt noch nicht aufgefallen. Allerdings wurden die ersten Test mit einem ande-

ren, ähnlichen Sensor durchgeführt. Bei den ersten Tests hat es sich zudem herausgestellt, dass

es sinnvoll ist, die Filter für die Angleichung der Koordinaten zu testen, in dem man Plotter für diese einsetzt. Aus diesem Grund wurde ein Java Plottertool entwickelt, dass zur visuellen

Überwachung des Datenstroms dient.

Bereits in einer frühen Phase hat sich herausgestellt, dass es beim Einsatz des Komplementär-

lters zu einer Abachung kommt, sodass man diesen alle paar Sekunden zurücksetzen musste.

Der Datenuss wies nach eine Weile regelmäÿig solche Abweichungen auf, so dass ein ande-

rer Komplementärlter zum Einsatz kam. Der PID-Regler war in seiner Implementation und

Kalibrierung am komplexesten. Die Stellwerte des Reglers waren am Anfang zu hoch einge-

stellt, dadurch neigte der Roboter stark zum übersteuern und damit zu einem ruckartigen

Fahrverhalten. Nach der schrittweisen Anpassung der Regelparameter sowie der Anpassung der

Motoransteuerung konnte auch dieses Problem gelöst werden. Zudem gab es noch die Probleme

mit verdrehten Koordinaten und groÿen Wertebereichen, die dazu führten, dass die Räder des

Roboters sich nicht in die gewünschte Richtung und nicht mit der berechneten Geschwindigkeit

gedreht haben. Nach dem Abschluss der Testphase hat sich herausgestellt, dass der PID-Regler

für diesen Prototypen nicht zwingend notwendig gewesen wäre. Der Kehrwert der Rotation, die

mit Hilfe des Gyrosensors ermittelt wird, ist zur Steuerung der Motoren ausreichend. Dennoch

ist das PID sehr hilfreich, gerade wenn der Prototyp weiterentwickelt, oder auf andere Umge-

bungen angepasst werden soll.

Der Zeitaufwand für die Prototyping- und die Testingphase wurde von unserem Team etwas

unterschätzt. Bei der nächsten Projektdurchführung wäre es sinnvoll, mehr Zeit für diese Pha-

sen einzuplanen, da wir den Zusammenhang zwischen der Interaktion des Prototypen mit der

Umwelt unterschätzt haben und immer wieder Anpassungen notwendig waren. Als Fazit lässt

sich ziehen, dass wir als Team viel über den Bereich Ubiquitous Computing gelernt haben und

vor allem unser Wissen im Bereich der Elektrotechnik, der Softwareentwicklung für Hardwa-

resysteme und die Grundlagen der Robotik ausbauen und erweitern konnten. Das Projekt hat

uns sehr viel Spaÿ gemacht und wir sind mit den ersten Erfolgen sehr zufrieden.

## 5 Sonstiges

### 5.1 Inbetriebname des Systems

1. Im ausgeschalteten Zustand liegt eines der Stromkabel frei. Schlieÿen Sie dieses an das
| korrekte Eingangsterminal des Stepdown Wandlers an (Rot auf +, Schwarz auf -). In der
| Regel sollte das andere der beiden Kabel noch in seinem vorgesehenen Terminal stecken,
| schieben Sie also das übrige Kabel in das anliegende Terminal und schrauben Sie es im
| Terminal fest.
2. Der Roboter wird nun durch mehrere LEDs signalisieren, dass er Strom bekommt. Stellen
| Sie den Roboter auf den vorgesehenen Ball und drücken Sie einmal auf den Reset Knopf
| des Arduino Controllers, damit der Roboter eine korrekte Kalibrierung vollführt.
3. Der Roboter wird sich nun kalibrieren. In der Standardeinstellung dauert dies etwa 5
| Sekunden, halten Sie den Roboter so lange still in der Ruheposition fest.
4. Nun können Sie versuchen, den Roboter langsam zu einer Seite des Balls zu kippen.
| Wenn er auf diese Neigung ruhig, aber mit genügend Kraft reagiert, ist der Roboter nun
| funktionsbereit!

## Anhang

Beigefügt zu diesem Dokument bendet sich der Ordner Anhang, in dem Sie den Quellcode des

Java Plotting Tools vornden. Des momentanen fehlenden Zugris halber werden die restlichen

Quellcode Snippets, wie z.B. die Testcodes für die Motoraufteilung, das PID, den Gyrosensor

und weiteres in naher Zukunft in einer github Repository zu nden sein. Bei Bedarf eines Links

zu diesem Repository, kontaktieren Sie uns einfach unter den Email Adressen auf der Titelseite.
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

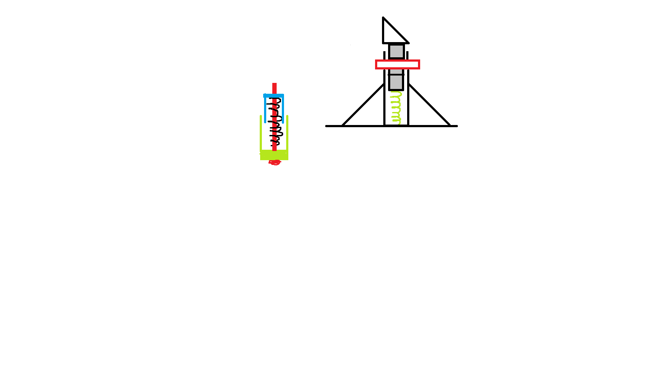
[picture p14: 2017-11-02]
cad/spring loaded damper design.png

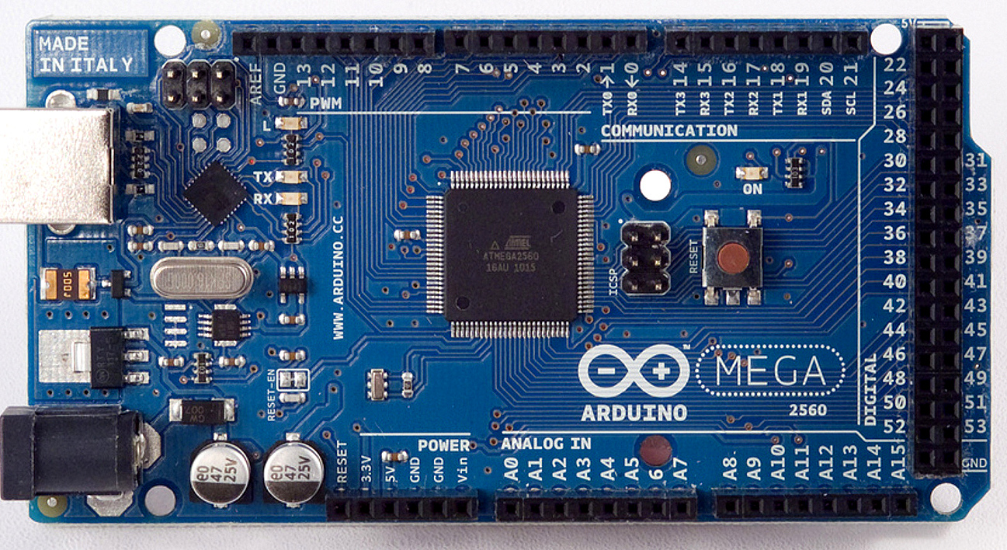
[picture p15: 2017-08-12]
cad/arduinomega2560_r2_front.jpg

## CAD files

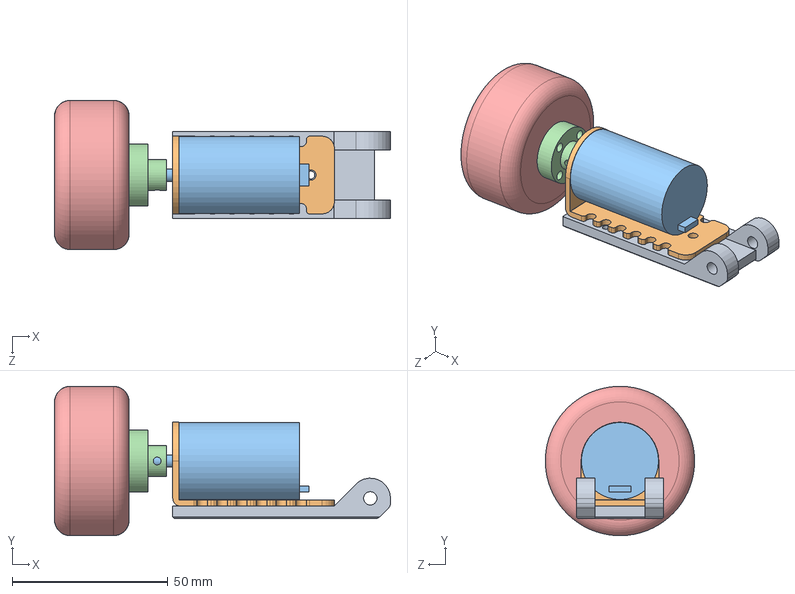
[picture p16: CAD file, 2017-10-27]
cad/Motor Assembly.SLDASM
108.0 x 48.0 x 48.0 mm
Motor Mount
Motor Mount Plate
Motor
WheelHub2
Wheel

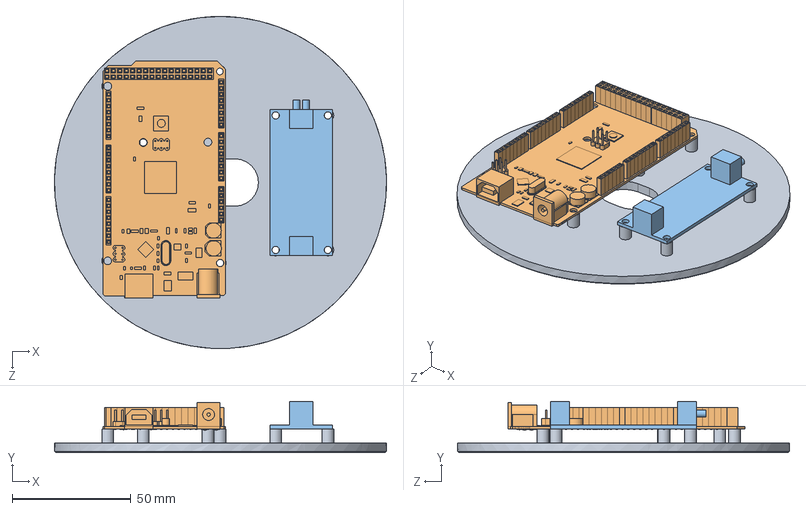
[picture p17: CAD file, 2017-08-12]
cad/PCB_Plate Assembly.SLDASM
139.9 x 21.5 x 140.0 mm
PCB_Plate
ArduinoMega2560
Stepdown PCB

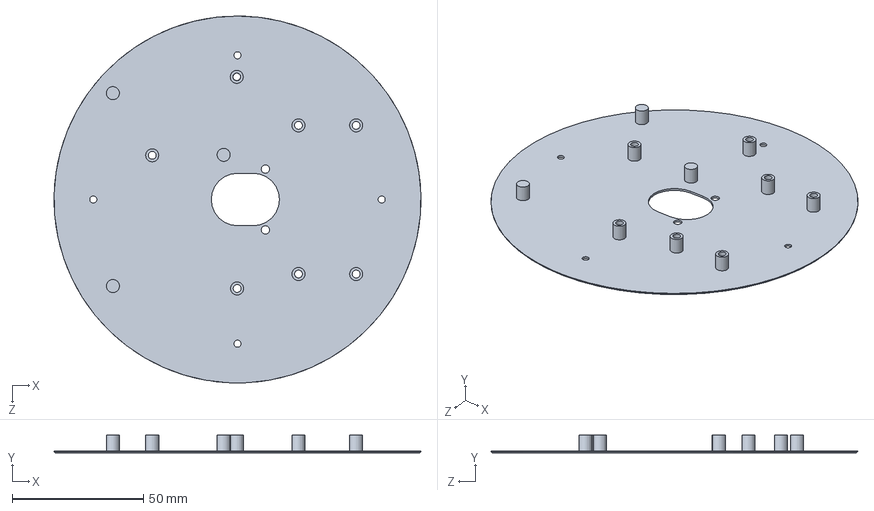
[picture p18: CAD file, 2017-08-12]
cad/thin plates/PCB_Plate Thin.SLDPRT
139.9 x 6.80 x 140.0 mm

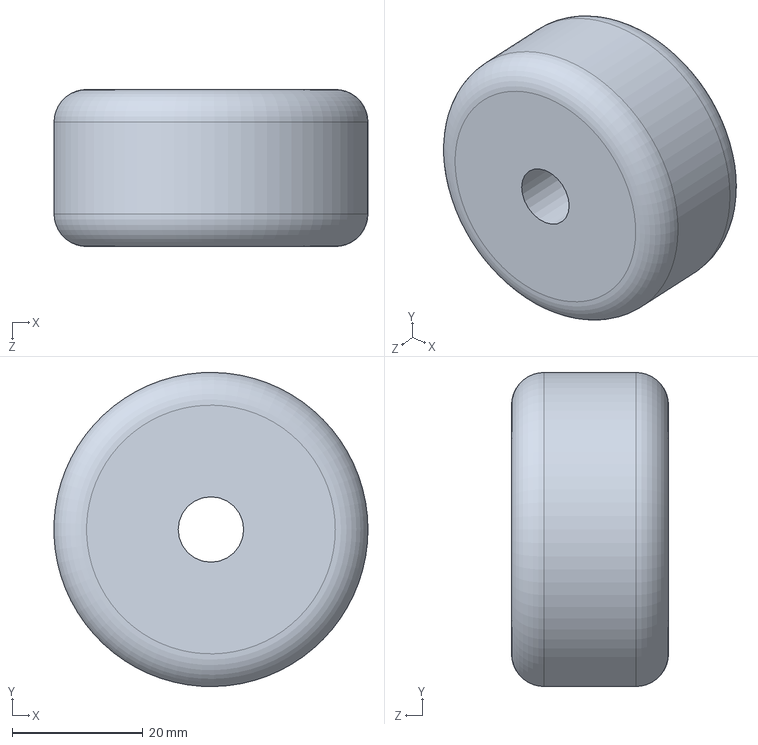
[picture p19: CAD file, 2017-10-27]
cad/Wheel.SLDPRT
48.0 x 48.0 x 24.0 mm

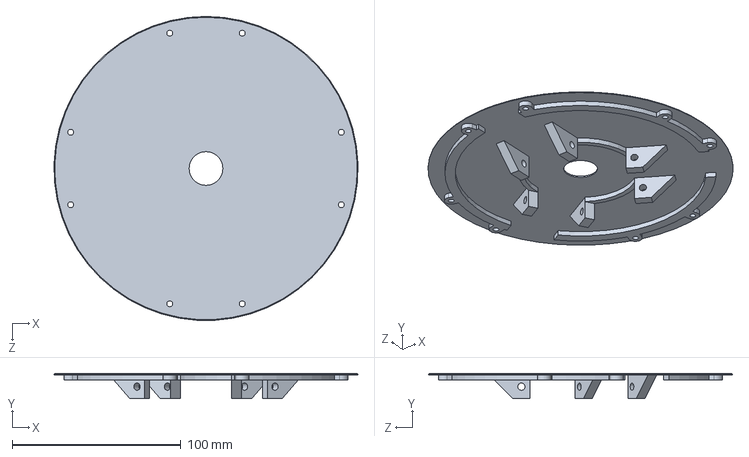
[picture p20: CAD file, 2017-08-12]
cad/thin plates/Bottom Plate Rework Thin.SLDPRT
179.9 x 14.8 x 180.0 mm

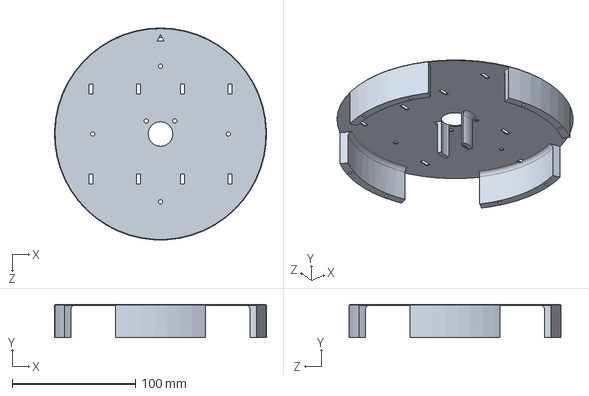
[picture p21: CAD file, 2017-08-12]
cad/thin plates/Top Plate Thin.SLDPRT
171.9 x 26.8 x 172.0 mm

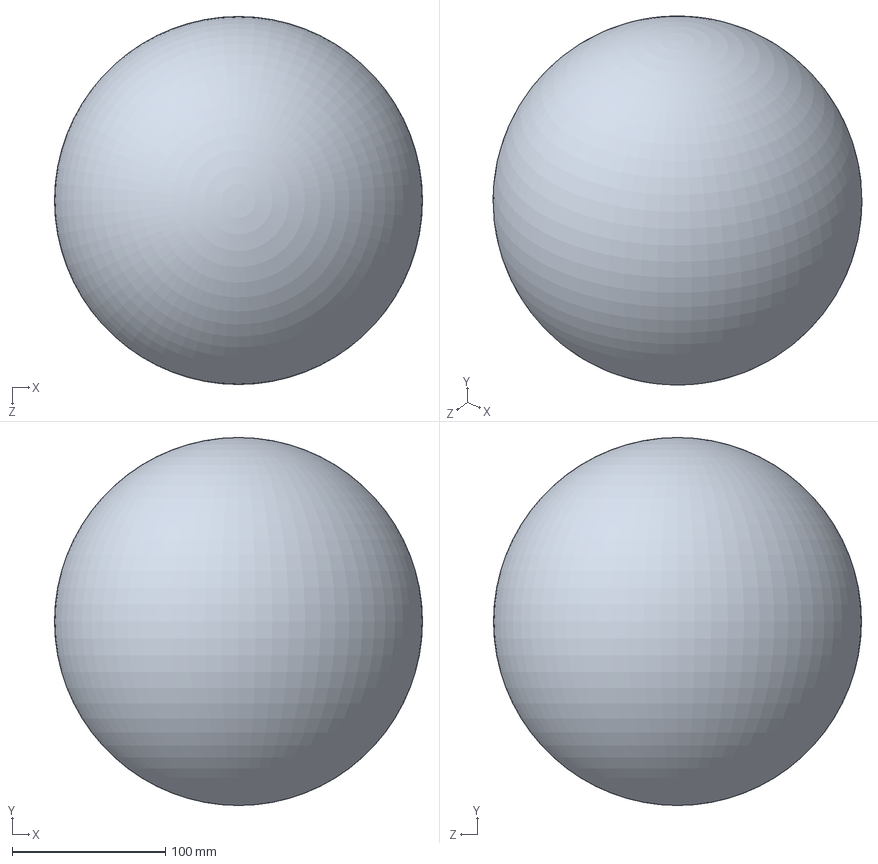
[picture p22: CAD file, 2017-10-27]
cad/24cm_ball.SLDPRT
240.0 x 240.0 x 240.0 mm

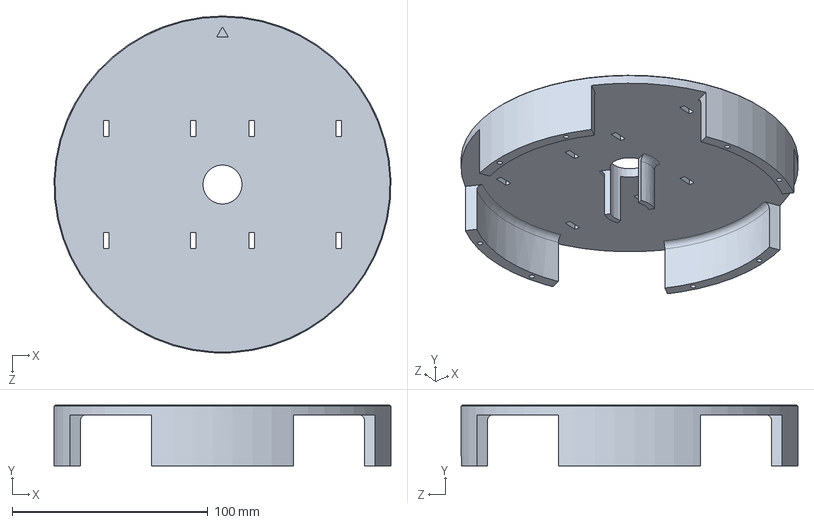
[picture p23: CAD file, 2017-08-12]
cad/Top Plate.SLDPRT
171.9 x 31.0 x 172.0 mm

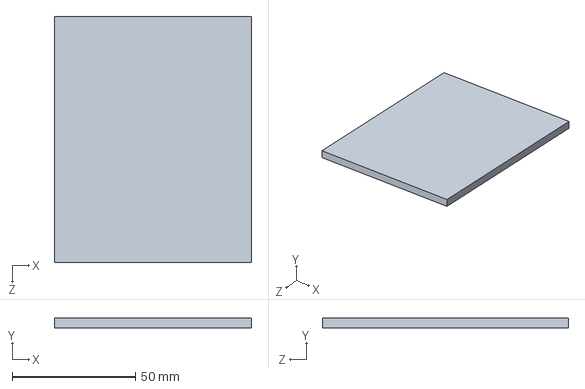
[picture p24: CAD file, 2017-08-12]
cad/PCB_Plate.SLDPRT
80.0 x 4.00 x 100.0 mm

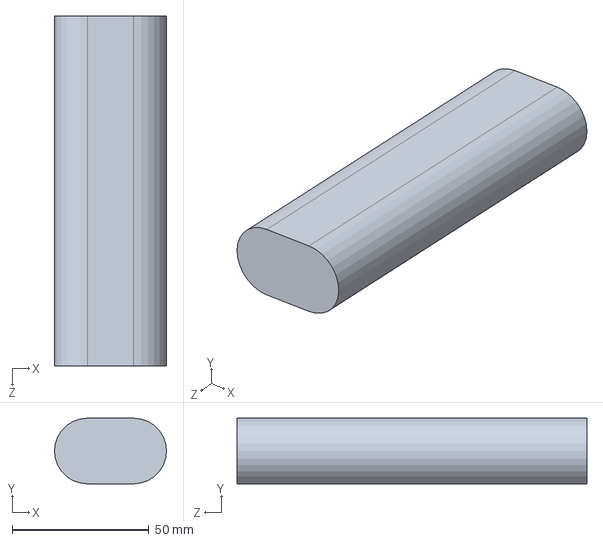
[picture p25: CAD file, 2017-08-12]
cad/Batterypack.SLDPRT
41.0 x 24.0 x 128.0 mm

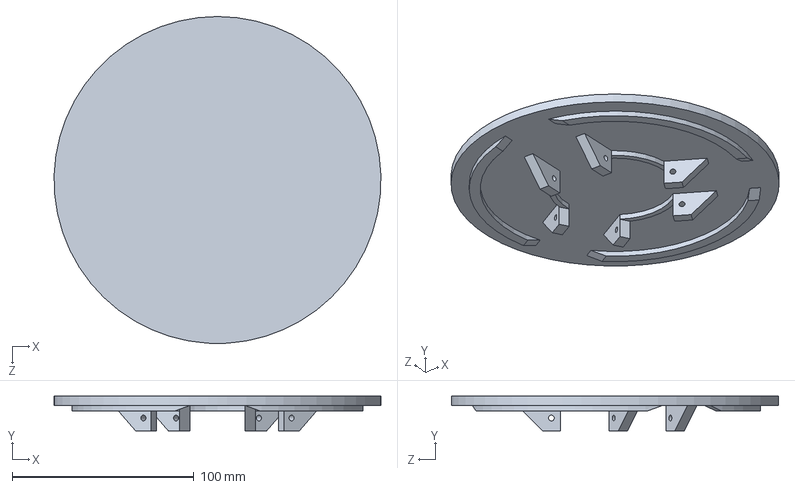
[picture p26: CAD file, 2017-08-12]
cad/Bottom Plate Rework.SLDPRT
179.9 x 19.0 x 180.0 mm

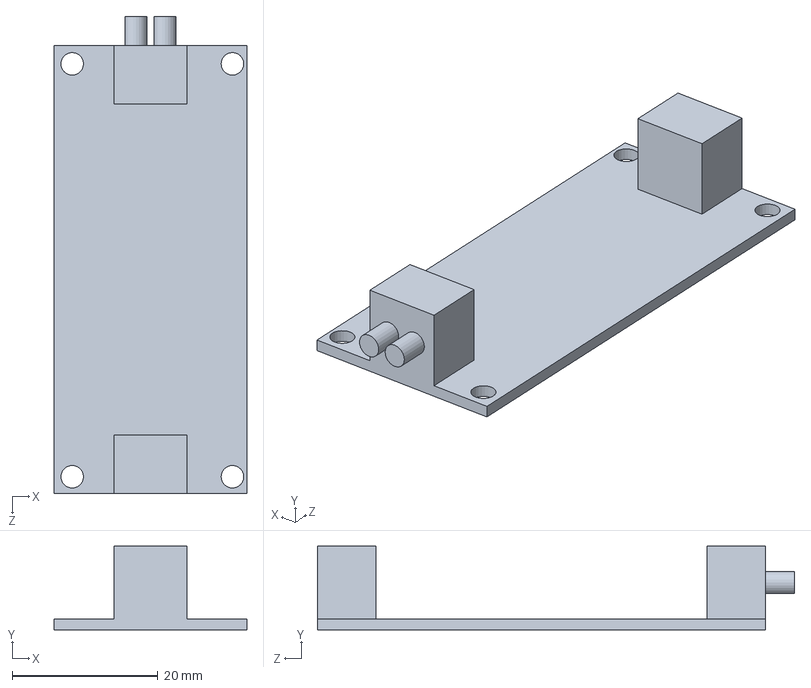
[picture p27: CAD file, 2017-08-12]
cad/Stepdown PCB.SLDPRT
26.5 x 11.5 x 65.5 mm

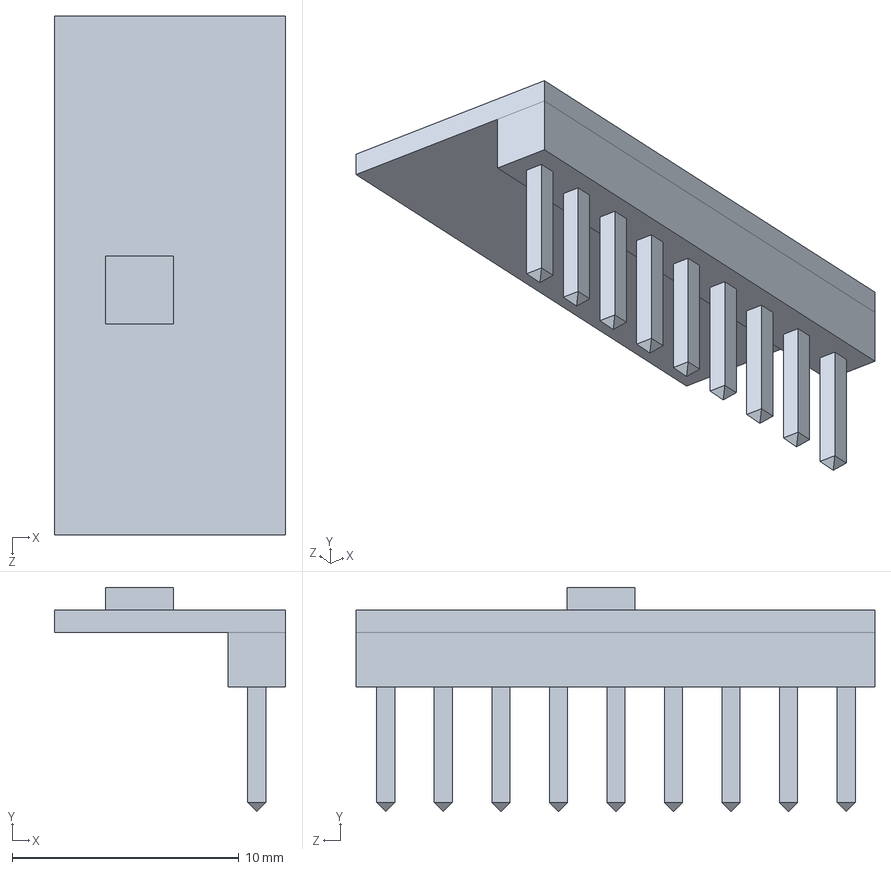
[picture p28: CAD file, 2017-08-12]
cad/IMU PCB.SLDPRT
10.2 x 9.90 x 22.9 mm

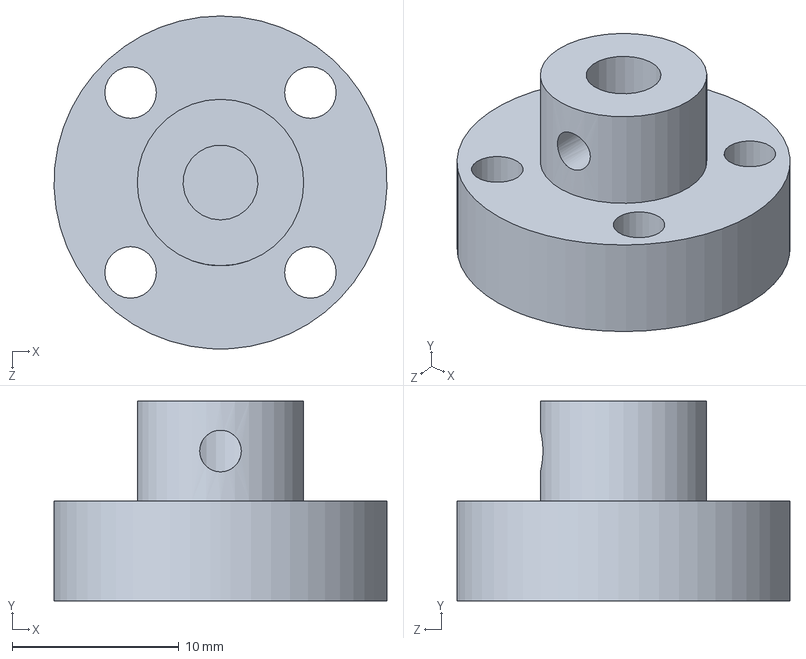
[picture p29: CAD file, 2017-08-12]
cad/WheelHub2.SLDPRT
20.0 x 12.0 x 20.0 mm

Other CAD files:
cad/Motor.SLDPRT
cad/Motor Mount Plate.SLDPRT
cad/Motor Mount.SLDPRT
cad/ArduinoMega2560.SLDPRT
cad/IMU_Tower Rework 2.SLDPRT
cad/old versions/Old Omniwheel/omniwheel-baugruppe.SLDASM
cad/old versions/Old Omniwheel/omniwheel-top.SLDPRT
cad/old versions/Old Omniwheel/omniwheel-top.STL
cad/old versions/Old Omniwheel/omniwheel-wheel-holder.SLDPRT
cad/old versions/Old Omniwheel/omniwheel-wheel-holder.STL
cad/old versions/Old Omniwheel/omniwheel-wheel.SLDPRT
cad/old versions/Old Omniwheel/omniwheel-wheel.STL
cad/old versions/Old Omniwheel/omniwheel.SLDPRT
cad/old versions/Old Omniwheel/omniwheel.STL
cad/old versions/Robot Construction 2/Bottom Assembly.SLDASM
cad/old versions/Robot Construction 2/Bottom Plate.sldprt
cad/old versions/Robot Construction 2/Motor Assembly.SLDASM
cad/old versions/Robot Construction 2/Motor Mount Plate.SLDPRT
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

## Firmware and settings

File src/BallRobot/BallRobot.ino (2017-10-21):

/* Inclusion of required files */
#include "gyro.h"
#include "pid.h"
#include "motor.h"

#define dt 10 // in ms

/* Object definitions and settings */
Gyro myGyro(dt);
PIDControl pid(1.0,0,0.005,-255,255,dt);
OmniMotorDriver omd;

/* Deadzone definition. With a rotation of less than this value,
 * the robot will stand still
 */
double deadzone = 1.5;

/* Buffers for timing, gyro data and PID outputs */
long lastMillis;
double xAngle, yAngle;
double xOut, yOut;

/* Main setup call 
 * Initializes Serial, the IMU and prepares the motor driver,
 * calbriates the IMU and enables the PID controller
 */
void setup() {
	pinMode(13, OUTPUT);
	Serial.begin(115200);
	if(!myGyro.init()) {

		while(1) {
			digitalWrite(13, HIGH);
			delay(1000);
			digitalWrite(13, LOW);
			delay(2000);
		}
	}

	
	myGyro.calibrate();
	omd.init();
	pid.enable();
}

/* Main loop 
 * The main loop connects all the libraries and classes together,
 * in that it describes the order of function calls that is necessary
 * for the function of the robot
 */
void loop() {
	/* Save the current point in time in lastMillis */
	lastMillis = millis();

	/* Get Data from Gyro */
	myGyro.update(&xAngle, &yAngle);

	/* Compute PID Output with the data */
	pid.compute(xAngle, yAngle, &xOut, &yOut);

	/* Plot Angle on Serial Plotter 
	Serial.print(xAngle);
	Serial.print(" ");
	Serial.print(yAngle);
	Serial.println(" "); */

  /* Plot Angle on Serial Plotter 
  Serial.print(xOut);
  Serial.print(" ");
  Serial.println(yOut); */

	/* If any calculated angle is larger than the deadzone */
	if(abs(xAngle) > deadzone || abs(yAngle) > deadzone) {

		/* Actually drive the motors */
		omd.drive(xOut, yOut);

	/* Otherwise, stop them */
	} else omd.stop();
	

	/* Wait until the next dt cycle
	 * if processing took less than dt, wait for the remaining time,
	 * otherwise wait for the next full cycle to start
	 * This is needed for gyro and PID accuracy
	 */
	int pTime = millis() - lastMillis;
	int resttime = (dt > pTime)? (dt - pTime) : 0;
	delay(resttime);
}

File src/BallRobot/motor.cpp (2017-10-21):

#include <Arduino.h>

#include "motor.h"


/* Drive all three motors, given the info of where (x,y) to go
 * This method calculates the angle difference between the
 * destination vector and the two angles (forwards and backwards direction) 
 * of each wheel and if the difference is less than 90°, the wheel is supposed
 * to rotate in that particular direction, the speed of which being interpolated
 * on a sine curve. Note: In this system, 0° is UP (along the y-axis) and the
 * angle increases counterclockwise. The Forward direction of the motors means
 * that it turns clockwise (right round) if you look along the motor body.
 * Params:
 * 	inputX:	The x-value of the 2D force vector that the robot is supposed to move to.
 * 	inputY: The y-value of the 2D force vector that the robot is supposed to move to.
 */
void OmniMotorDriver::drive(double inputX, double inputY) { 
	float forceAngle = calcAngle(inputX, inputY);

	/* Calculates the relative speed distribution on all three wheels */
	calcDistribution(forceAngle);

	/* Calculates the force (length) of the direction vector */
	float force = calcLength(inputX, inputY);

	/* Multiply relative speed by force for each motor and 
	 * call the driveSingle method to actually turn them.
	 */
	for(int motor = 0; motor < 3; motor++) {
		wheelSpeeds[motor] = wheelRelSpeeds[motor] * force * motorGain;
		driveSingle(motor, wheelSpeeds[motor]);
	}

	/* Print some values for debugging purposes. Viewable in the Arduino IDE Serial plotter 
	Serial.print(wheelSpeeds[0]);
	Serial.print(" ");
	Serial.print(wheelSpeeds[1]);
	Serial.print(" ");
	Serial.println(wheelSpeeds[2]);*/
	
}

/* Motor driver init method
 * Loops through the 2D array containing the direction and pwm pins of each motor
 * and initializes them as output. Also sets all the motor speeds to 0 by calling the stop() method.
 */  
void OmniMotorDriver::init() {
	for(int motor = 0; motor < 3; motor++) {
		for(int pinType = 0; pinType < 2; pinType++) {

			int pinNumber = motorPins[motor][pinType];
			pinMode(pinNumber, OUTPUT);
		}

		stop();
	}
	
} 

/* Method for driving a single motor 
 * Uses the given parameters (motor number and speed) to drive a single motor.
 * This method also contains some special calculations and number range transformations
 * that are needed to send the correct values to the motor.
 * Params:
 * 	motor:	[0-2] The number of the motor. Looking from the top back, the motors are numbered
 *		clockwise from the top left one starting with 0. Top right is 1 and back motor is 2.
 * 	speed:	[-255 - 255] Combined value for motor speed and direction (thus can be negative).
 */
void OmniMotorDriver::driveSingle(int motor, double speed) {
	/* Retrieve the required pin numbers */
	int pwmPin = motorPins[motor][0];
	int dirPin = motorPins[motor][1];

	/* Determine the reverse state and make the speed value positive */
	int reverse = (speed < 0)? HIGH : LOW;
	int speedAbs = abs(speed);

	/* Invert the speed value (needed for FIT0441 motors) and cap it to [0-255] */
	int pwm = max(255 - speedAbs,0);

	/* Write the speed and reverse data to the actual pins */
	analogWrite(pwmPin, pwm);
	digitalWrite(dirPin, reverse);
}

/* Stops all three motors (sets speeds to 0) */
void OmniMotorDriver::stop() { 
	for(int motor = 0; motor < 3; motor++) {
		driveSingle(motor, 0);
	}
}

/* Calculates the relative speed distribution on all three wheels 
 * that has to happen for the robot to move in the given direction. 
 * Params:
 * 	degAngle:	Angle in degrees in the agreed upon coordinate system (Read above).
 *			The angle indicates the final moving direction.
 */	
void OmniMotorDriver::calcDistribution(float degAngle) {
	/* Loop through each wheel and each of the two directions of them */
	for(int wheel = 0; wheel < 3; wheel++) {
		for(int dir = 0; dir < 2; dir++) {

			/* Get the angle at which this direction of the wheel is "pointing" */
			float curWheelAngle = wheelAngles[wheel][dir];

			/* Calculate the difference between the direction vector and the wheel direction */
			float phi = fmod(abs(curWheelAngle - degAngle),360);
			float angleDiff = phi > 180 ? 360 - phi : phi;

			/* If its < 90°, the wheel has to turn in that direction.
			 * On exactly 90° the wheel wouldn't turn at all and
			 * on more than 90°, the wheel's other direction will be < 90° anyway 
			 */
			if(angleDiff < 90) {
				wheelRelSpeeds[wheel] = sin(toRadians(90 - abs(angleDiff)));
				if(dir == 1)
					wheelRelSpeeds[wheel] = -wheelRelSpeeds[wheel];
			}  
		}
	}
}

/* Calculate the angle of a 2D origin vector (x,y) in the agreed upon coordinate system (Read above)
 * Params:
 * 	x:	x-value of the direction vector of which to calculate the angle of
 * 	y:	y-value of the direction vector of which to calculate the angle of
 * Returns:
 *	Float value storing an angle (in degrees)
 */	
float OmniMotorDriver::calcAngle(float x, float y) { 
	return fmod(toDegrees(atan2(y, x)) + 270, 360);
}

/* Calculate the length of a 2D origin vector (x,y)
 * Params:
 * 	x:	x-value of the direction vector of which to calculate the length of
 * 	y:	y-value of the direction vector of which to calculate the length of
 * Returns:
 *	Float value storing a length of the given vector
 */
float OmniMotorDriver::calcLength(float x, float y) { 
	return sqrt(x*x + y*y);
}

/* Convert angles given in radians into a degree format
 * Params:
 * 	radians: An angle in a radians number format
 * Returns:
 *	Float value storing an angle (in degrees).
 */
float OmniMotorDriver::toDegrees(float radians) { 
	return radians / 2 / PI * 360;
}

/* Convert angles given in degrees into a radians format
 * Params:
 * 	degrees: An angle in a degrees number format
 * Returns:
 *	Float value storing an angle (in radians).
 */
float OmniMotorDriver::toRadians(float degrees) { 
	return degrees / 360 * 2 * PI;
}

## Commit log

2017-08-12 initial file upload
    [Alu_Extrusion.SLDPRT, ArduinoMega2560.SLDPRT, Battery Pack Assembly.SLDASM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]
2017-08-12 updated arduino code documentation
2017-10-09 Gyro inaccuracy bugfix
2017-10-21 Motor Inversion Bugfix
2017-10-27 Added ball and wheel CAD files
    [24cm_ball.SLDPRT, Bottom Plate Rework Assembly.SLDASM, Motor Assembly.SLDASM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]
2017-11-02 beautiful mockup of spring damper in paint
